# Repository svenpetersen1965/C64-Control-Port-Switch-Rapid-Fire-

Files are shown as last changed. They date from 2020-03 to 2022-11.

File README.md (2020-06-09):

# C64-Control-Port-Switch-Rapid-Fire-
This is a Control Port Switch for the Commodore C64. It provides a rapid fire function. Other than an auto fire function, it fires only as long as the fire button is pressed. And the firing is synchronized with pressing this button. The delay is <= 1msec - the human reaction time is about 300msec.

The micro controller is a (Arduino) Pro Micro. This way, no fancy tools are required for uploading the firmware (just a micro usb B cable).

Find some info on the required cable making <a href="http://tech.guitarsite.de/cable_making.html">on my website</a>

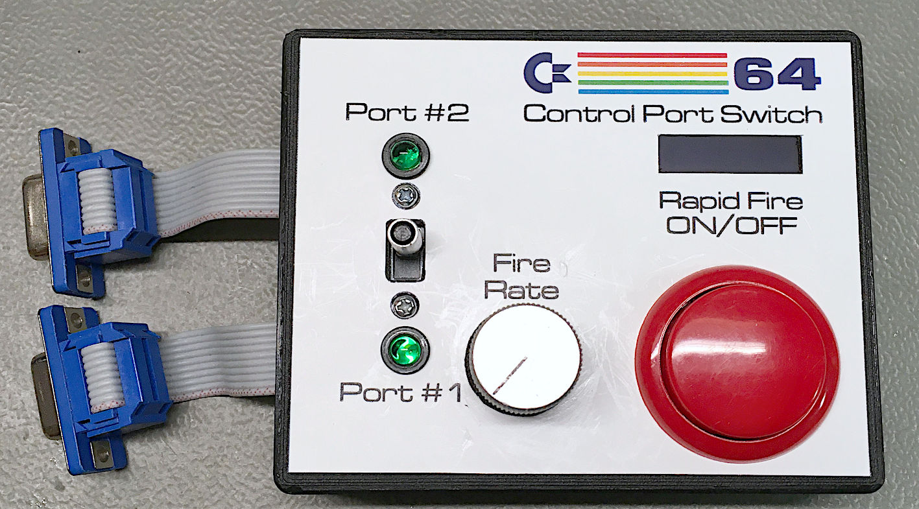
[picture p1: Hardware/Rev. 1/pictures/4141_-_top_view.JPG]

Completed project

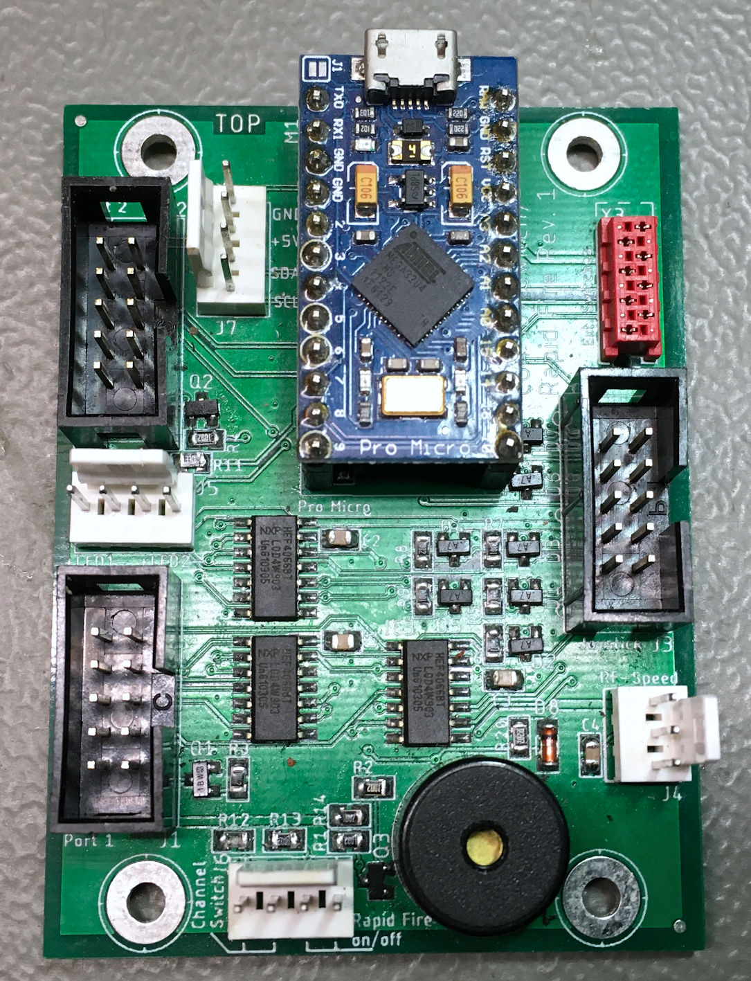
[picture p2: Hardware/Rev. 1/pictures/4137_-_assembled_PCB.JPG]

The PCB

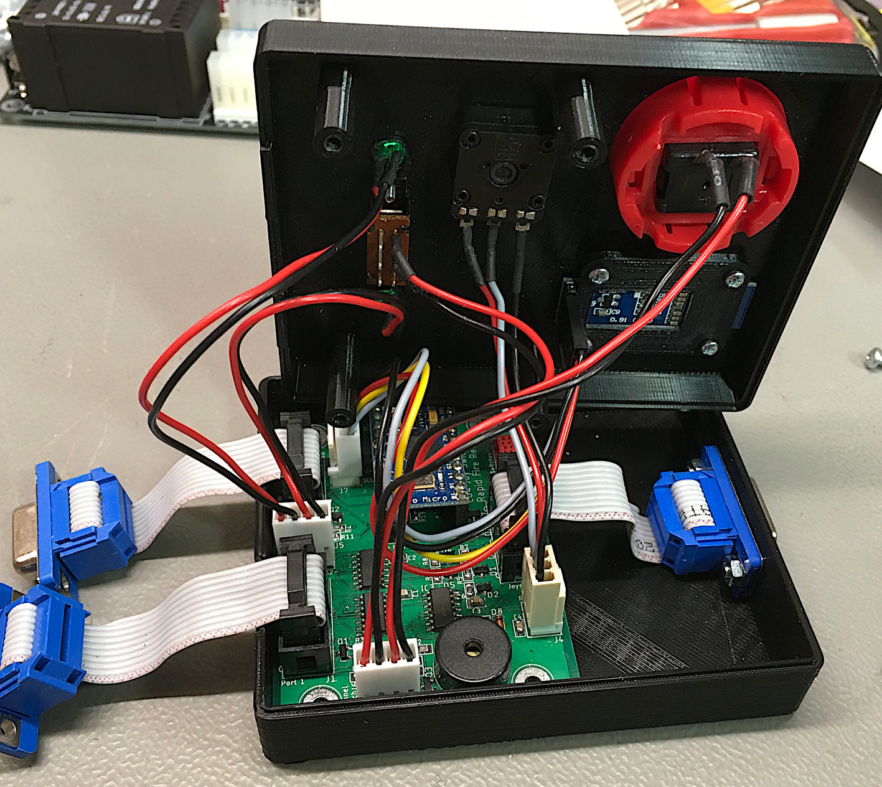
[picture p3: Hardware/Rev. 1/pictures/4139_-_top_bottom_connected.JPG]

The guts

# Recommended Screws
Those are mentioned in the documentation.

# Component Price
The price for the components and PCB was calculated. It is 20.49€ without the 3D printed case (as of June 8th, 2020). The components can be bought cheaper, in case the Pro Micro is bought from AliExpress or Ebay (non domestic).

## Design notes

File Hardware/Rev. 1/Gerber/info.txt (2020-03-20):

      
       Board: C64_Joyswitch_RF
       Rev.:  1
  
       Files:
       ======
  
       All Gerber files are generated in extended gerber format (RS274X)
       *.TOP        : Film top copper
       *.BOT        :  -"- bottom copper
       *.STC        :  -"- top soldermask 
       *.STS        :  -"- bottom soldermask
       *.PLC        :  -"- silk screen top
       *.CRC        :  -"- cream top
       *.DK         : Drills plated Through (Excellon)
       *.NDK        : Drills not plated Through (Excellon)
       *.OUT        : Board outline

       Board Size:
       ===========
       Length     :   72.0 mm
       Width      :   55.0 mm
       Thickness  :   1.6 mm
       Material   :   FR 4
       Copper     :   35 um
       Surface    :   HASL
       
       Remarks:
       ========

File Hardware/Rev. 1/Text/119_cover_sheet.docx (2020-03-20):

Project Documentation

C64 – Joystick Switch & Rapid-Fire

Project number: 119

Revision: 1

Date: 18.03.2020

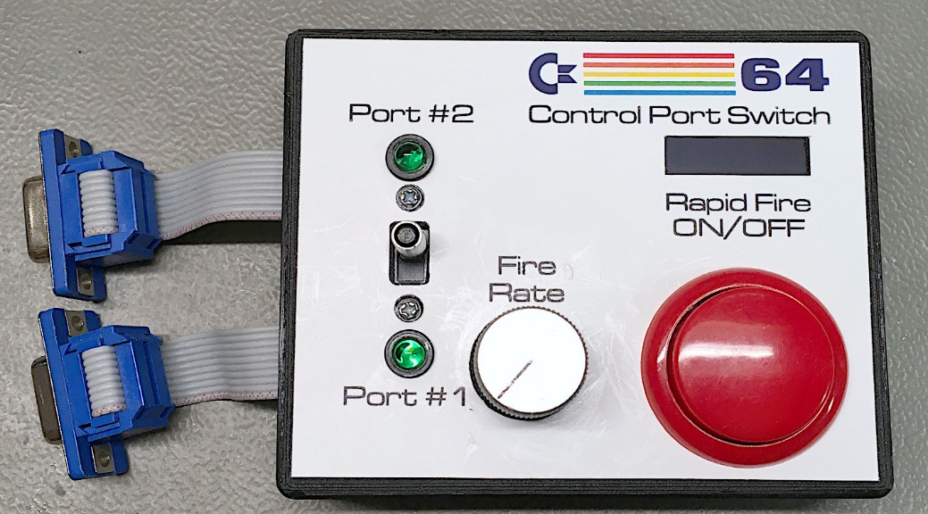
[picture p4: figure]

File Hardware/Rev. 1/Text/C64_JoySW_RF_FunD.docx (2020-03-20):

C64 – Control Port Switch & Rapid-Fire Rev. 1

Functional Description

J1 connects top Control Port 1, J2 to Control Port 2. The switching functionality to the four direction channels (JOY0…3) of the joystick is realized in IC1 and IC2. A HIGH level on signal PORT1 switches on the analog switches of IC1 to the active state, while IC2 is switched off. The joystick signals are available on J1 (JOYA0…3).

A HIGH level on signal PORT2 switches IC1 off (PORT1 is the inverted PORT2), while IC2 is switched on. JOY0…3 are now present on JOYB0…3 (J2, Port 2).

The analog signals POTX and POTY are switched with the analog switch IC2. Q3 and R1 invert the signal PORT2. A HIGH level on the resulting Signal PORT1 is switching POTX to POTXA and POTY to POTYA on control port 1.

A HIGH level on PORT2 switches POTX to POTXB and POTY to POTYB (control port 2).

Both Fire signals (FIREA and FIREB) are generated by the micro controller module M1, a Pro Micro. Q1 and Q2 serve as switches. HIGH pulses on the signals FIRE1 and FIRE2 respectively issue LOW pulses on FIREA and FIREB respectively. LOW means, that the fire is active.

/LED1 and /LED2 should indicate the active control port. /SWITCH and /RF_ON are active LOW signals from external switches, the purpose is switching between channels and switching on/off the rapid-fire function.

The FIRE signal is issued by the connected joystick. It is active LOW. The controller is supervising this signal and issuing the HIGH level or pulses on FIRE1 or FIRE, depending on the rapid-fire option is switched off or on and the port, which is selected.

The signal RFSPEED is a voltage level depending on the position of the connected “Speed” potentiometer. The controller is converting it to digital internally.

J7 carries the I²C bus signals of the controller and supply voltage (+5V) and ground. The purpose is connecting an I²C bus LCD or OLED display. This can serve to indicate the state and rapid-fire rate.

The twin diodes D1…D7 serve as a basic protection of the joystick input. The digital joystick inputs are connected to 10k pull-up resistors.

IC4 is not necessarily populated. It is an EEPROM and can be used to store parameters that should be non-volatile. It is only required, if the scrip for the Pro Micro supports this feature.

The circuitry around Q5 is driving a piezo buzzer. It is an option and only required, in case the firmware (script) for the Pro Micro supports this feature.

C64_JoySW_RF_FunD.docx 18.03.2020 21:15 Drafted by Sven Petersen Page 2 of 2 Doc.-No.: 000-6-00-00

C64_JoySW_RF_FunD.docx 18.03.2020 21:15 Drafted by Sven Petersen Page 1 of 1 Doc.-No.: 119-6-02-01

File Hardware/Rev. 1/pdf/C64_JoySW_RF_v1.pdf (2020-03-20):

# Project Documentation

## C64 – Joystick Switch & Rapid-Fire

## Project number: 119

## Revision: 1

## Date: 18.03.2020

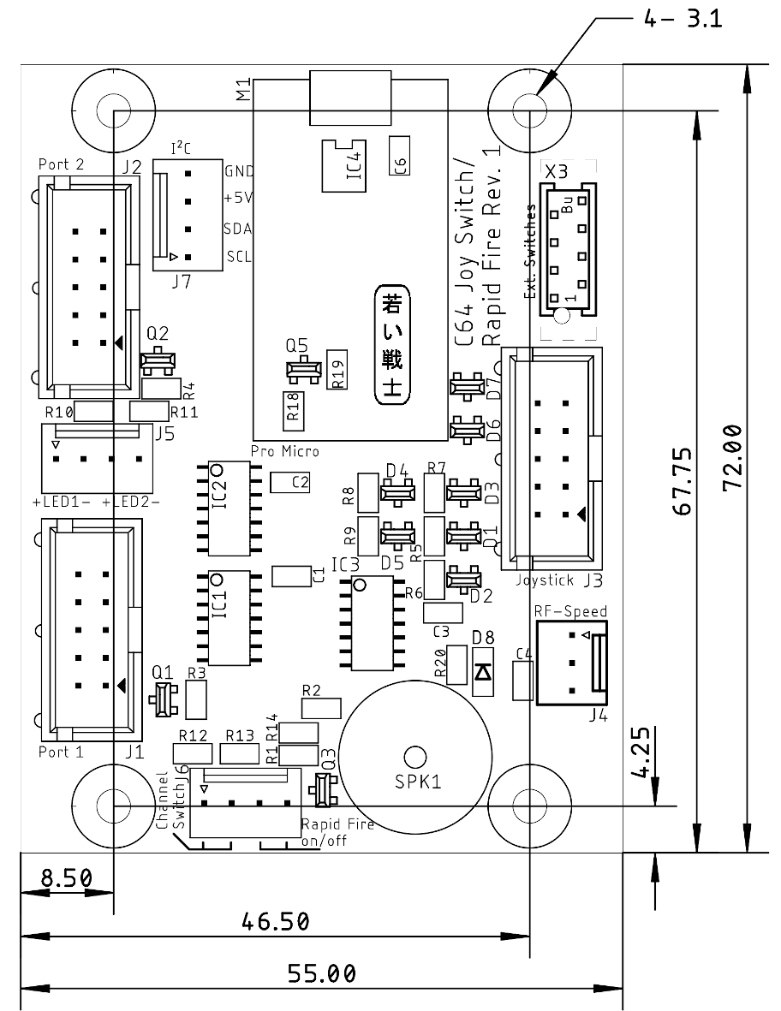
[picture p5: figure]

C64_JoySW_RF_ModD.docx | | 20.03.2020 15:00
Drafted by Sven Petersen | Page 1 of 16 | Doc.-No.: 119-6-01-01

### C64 – Control Port Switch & Rapid-Fire Rev. 1

### Module Description

Most C64 games require the joystick being connected to Control Port 2. Some games, especially those written in the early years of the C64, want the joystick on Control Port 1. To save the hassle of connecting the joystick back and forth, this joystick switch is does it on pressing a button. The selected port is displayed with an LED. The POTX and POTY signal for the paddles is switched as well.

Also, a rapid-fire function is implemented, which is synchronized to the fire button. That means, it starts firing immediately after the fire button was pressed (the maximum delay is 1 ms) at an adjustable frequency. This way, an optimized frequency can be set for every game individually.

The micro controller, which is used in this project is a Pro Micro. They are available for cheap on Ebay and from other online shops, they can be programmed with the free Arduino Software and only a Micro-USB cable is required for the in-system programming of this controller. A I²C connection allows to connect an OLED display to visualize the fire rate.

Figure 1: Dimensions of the PCB

A 3D printed case is provided with the project data. Alternatively it fist into the Reichelt RND
455-00959.

For future expansions, a serial (I²C) EEPROM (IC4) can be installed as a non-volatile memory. Also, the connector X3 is not required.

## Programming the Pro Micro

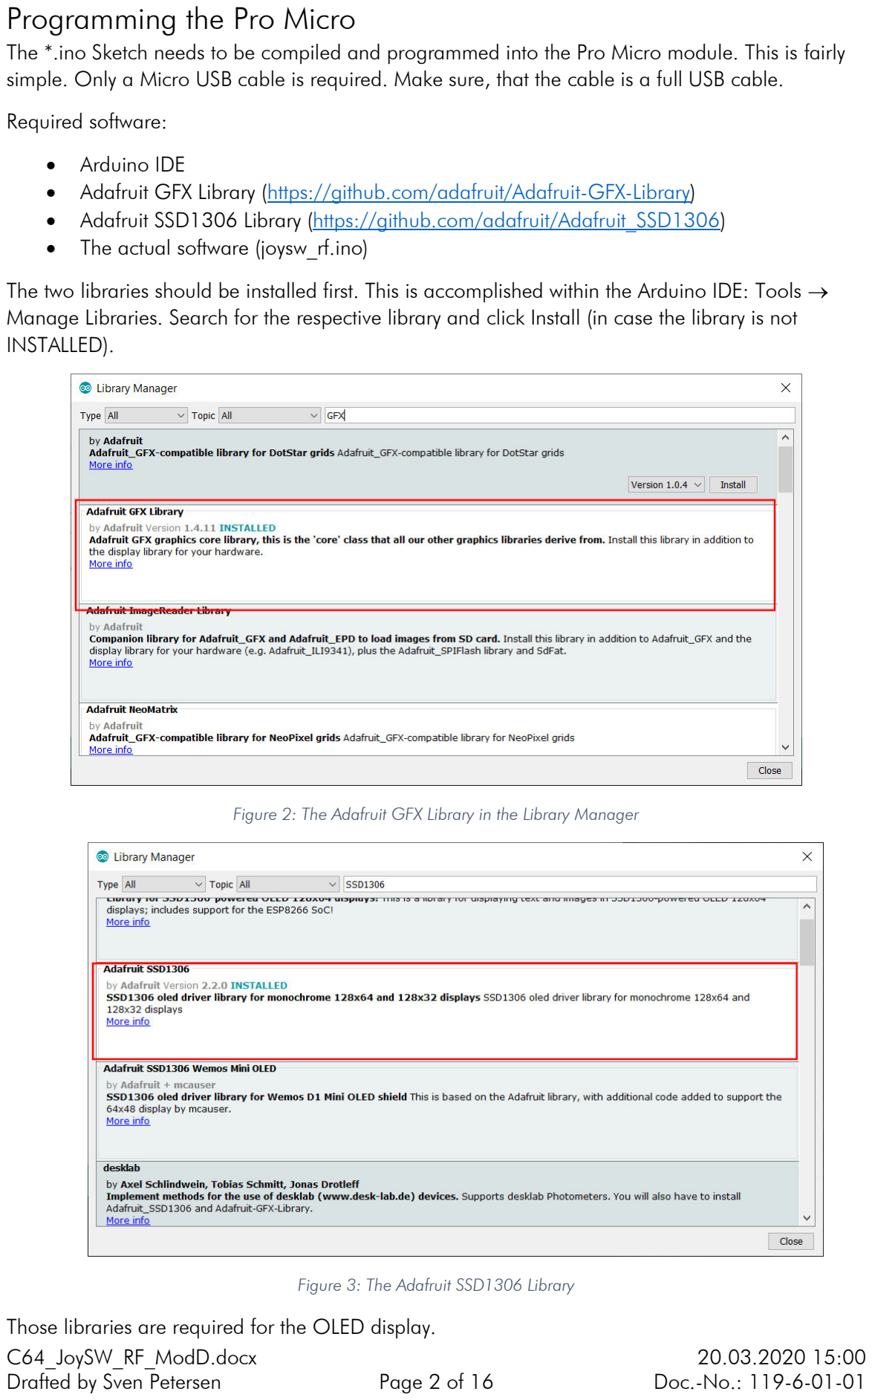
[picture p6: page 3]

Drafted by Sven Petersen | Page 2 of 16 | Doc.-No.: 119-6-01-01

The *.ino Sketch needs to be compiled and programmed into the Pro Micro module. This is fairly simple. Only a Micro USB cable is required. Make sure, that the cable is a full USB cable.

Required software:

- Arduino IDE
- Adafruit GFX Library (https://github.com/adafruit/Adafruit-GFX-Library)
- Adafruit SSD1306 Library (https://github.com/adafruit/Adafruit_SSD1306)
- The actual software (joysw_rf.ino)

The two libraries should be installed first. This is accomplished within the Arduino IDE: Tools → Manage Libraries. Search for the respective library and click Install (in case the library is not INSTALLED).

Figure 2: The Adafruit GFX Library in the Library Manager

Figure 3: The Adafruit SSD1306 Library

Those libraries are required for the OLED display.

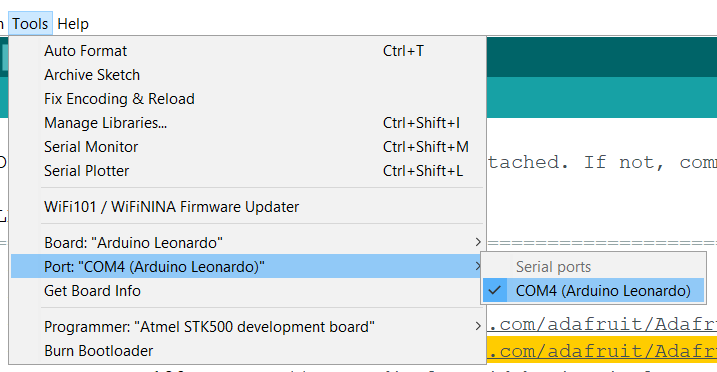
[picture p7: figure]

Drafted by Sven Petersen | Page 3 of 16 | Doc.-No.: 119-6-01-01

Next is selecting the type of Arduino. The Pro Micro is acting like a Leonardo. So in the Arduino IDE, you have to select Tools → Board → Arduino Leonardo.

Now make sure, that Pro Micro is connected to the PC via the USB cable (Micro USB). It does not need to be installed in the Control Port Switch. It is powered via USB.

Figure 4: Setting up the board type (Leonardo)
After connecting the Pro Micro, the PC should report a new device is connected. The Pro Micro’s programming interface acts as a serial interface (COM-Port). If not, there might be a problem with the drivers or the Pro Micro is broken.

Now, try to find the COM-Port number, that the Pro Micro is configured as:

Figure 5: Selecting the COM-port
In Tools → Port, this COM-port should be visible. Select it. The COM-port is the serial channel, the Arduino IDE is communication through with the ATmega 32u4 micro controller on the module.

Now you can load the Sketch into the Arduino IDE (File → Open…). The Sketch is the source code of the program. It needs to be compiled (to create a machine program, which the processor understands). In the Arduino IDFE, it is very much simplified. You do not need to care for make-files etc. like in other development environments for micro controllers. If you are not into this topic, Arduino is for you.

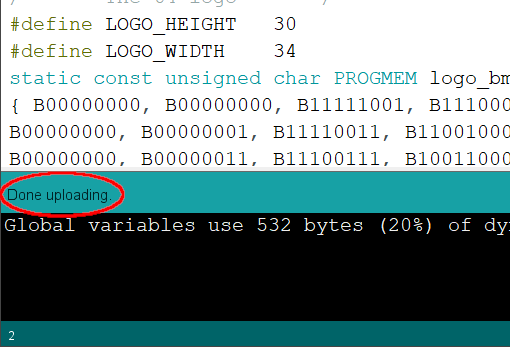
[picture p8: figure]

Drafted by Sven Petersen | Page 4 of 16 | Doc.-No.: 119-6-01-01

You can even edit the source code. In case you do not want to connect a display (which is recommended), you can put // in front of the #define OLED directive. This makes a comment out of it, so it is not effective anymore. You will see a // comment at almost every line. Feel free to look though it, you might find it interesting. Programming is no witchcraft!

So, to compile and upload the sketch, click the right arrow icon at the top left of the Arduino IDE.

Figure 6: Compiling the Sketch and uploading (right arrow)

If all libraries are installed, the correct board type and COM-Port is selected and the Sketch is unmodified, the code should compile and upload without any error messages.

Figure 7: The Upload is done
So, look out for “Done uploading”, like shown in Figure 7. If you don’t see this message, you
should read the error messages, which are displayed in the bottom of the window.

## Wiring the Device

### Crimping

Crimping is the preferred way of making cables, the connections are of a good quality (if the crimping carried out well). Unfortunately, it requires some dedicated tools. Fortunately, there are tools available for a fair price. Good results can be accomplished with the Engineer PA-20 and PA-09 tools. The IWISS IWS-2820 is a cheaper alternative, the results are acceptable.

Those tools are two pass tools. That means, the wire crimp and the isolation crimp have to be
carried out in two consecutive passes. I prefer the “wire crimp first” method. There are plenty video

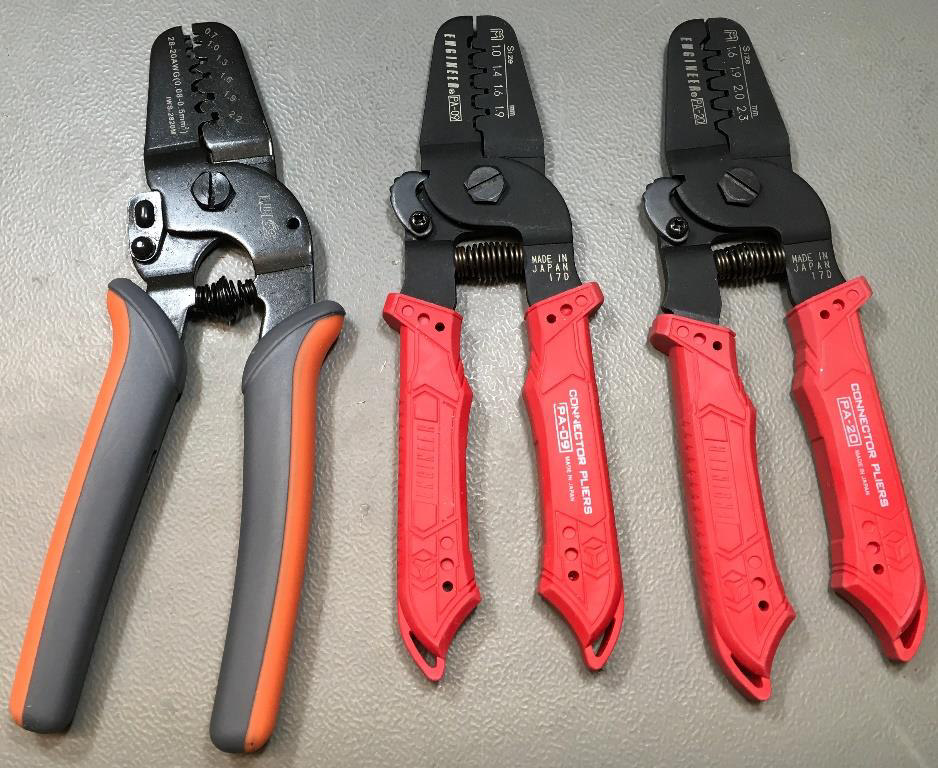
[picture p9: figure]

Drafted by Sven Petersen | Page 5 of 16 | Doc.-No.: 119-6-01-01

tutorials about crimping on Youtube. I also plan to write an essay about crimping on my website (http://tech.guitarsite.de). This is a future project.

Figure 8: My crimp tools (from left to right: IWS-2820, PA-09, PA-20)

After 25 years in industrial engineering, I prefer locking connectors. The widely popular DuPont connectors are also acceptable for hobby projects. They might need to be secured with a drop of silicon glue (hot glue might work, but is harder to separate, if required).
Direct soldering of the wires onto the board, is also a working method, if you don’t have any crimp tools or don’t want to invest in them. It is not really great and it is hard to separate the components
of the built, if required.

### Cables

Figure 9: 2x5 and DSub IDC connectors and strain reliefs

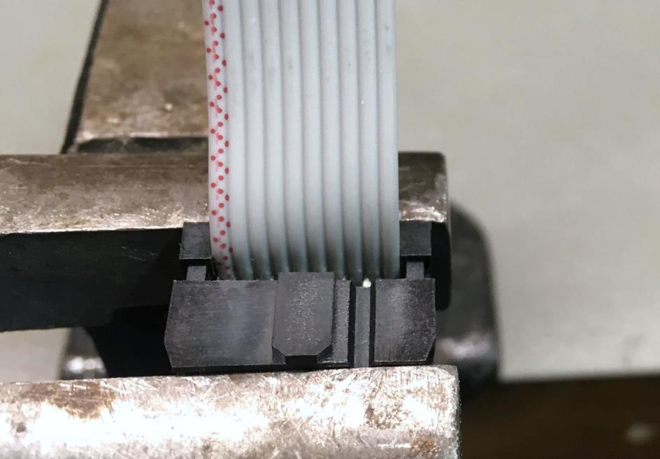
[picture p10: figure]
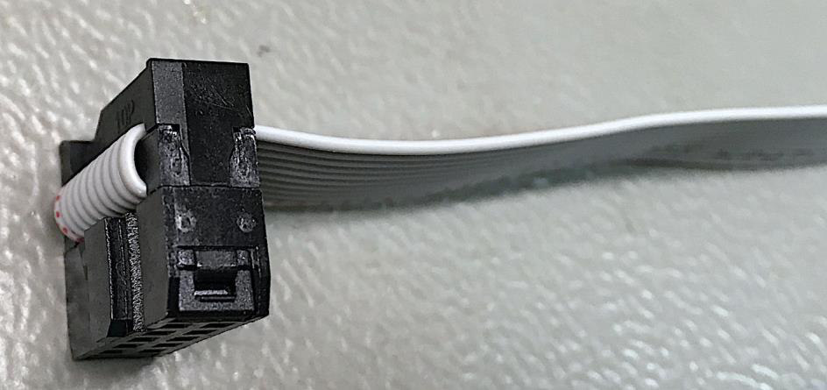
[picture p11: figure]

Drafted by Sven Petersen | Page 6 of 16 | Doc.-No.: 119-6-01-01

There are three ribbon cables, two for the control ports, one for the joystick input. Both types of connectors are IDC (Insulation Displacement Connectors). (https://en.wikipedia.org/wiki/Insulation-displacement_connector) This means, no soldering required, easy make. The little blades on each pin will penetrate the insulation of each wire of the ribbon cable and make a reliable contact with the conductors. It is a technology, which is established since the 1970s.
You don’t even need a special tool for making the cables, just a (little) vice (Figure 10). There is a
strain relief for both connectors, which is installed last. First, you cut the ribbon cable to length. Then insert the ribbon cable and align to the opposite side of the connector. Keep in mind, that installing the strain relief will cause a 180° turn (Figure 11). So, insert the cable from the opposite side that you finally want the cable to leave the connector. Pin 1 is marked. The wire 1 is also marked on a ribbon cable.

All D-Sub 9 connectors only have 9 pins, the IDC connectors have 2x5 (=10) pins. Thus the 10th wire has to be separated before the cable is inserted (Figure 12) in the D-Sub and finally clipped off.

Figure 10: IDC connector before being compressed in a vice

Figure 11: Side view after installing the strain relief

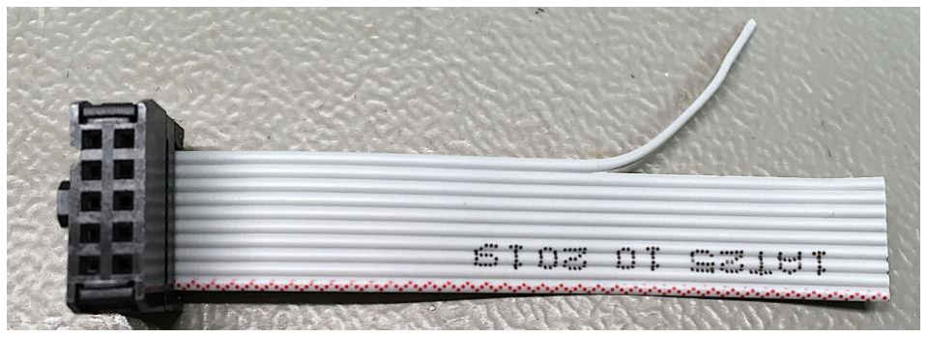
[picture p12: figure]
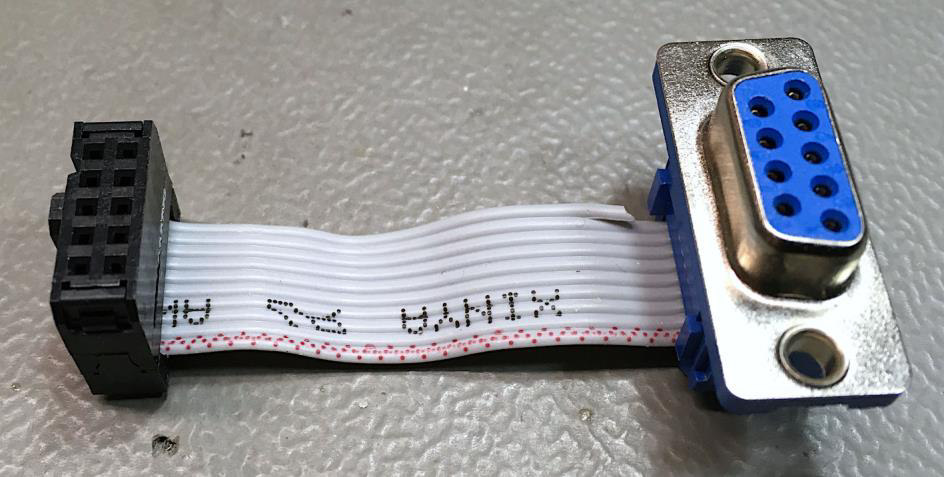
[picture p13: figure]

Drafted by Sven Petersen | Page 7 of 16 | Doc.-No.: 119-6-01-01

Figure 12: Separated 10th wire of the ribbon cable

Keep in mind, that pin 1 is in a deferent position on male and female D-Sub connectors. On a female connector, the pin numbers are usually shown on the contact face.

The required ribbon cables look like this:

Figure 13: Joystick Input cable: Male D-Sub, 8cm ribbon cable

Figure 14: The output cables: female D-Sub, 8cm ribbon cable

Please note the different orientation of the coding notch in Figure 13 and Figure 14. Also, the marked wires (1) of the ribbon cables are on opposite sides. The cable shown in Figure 14 is required twice.

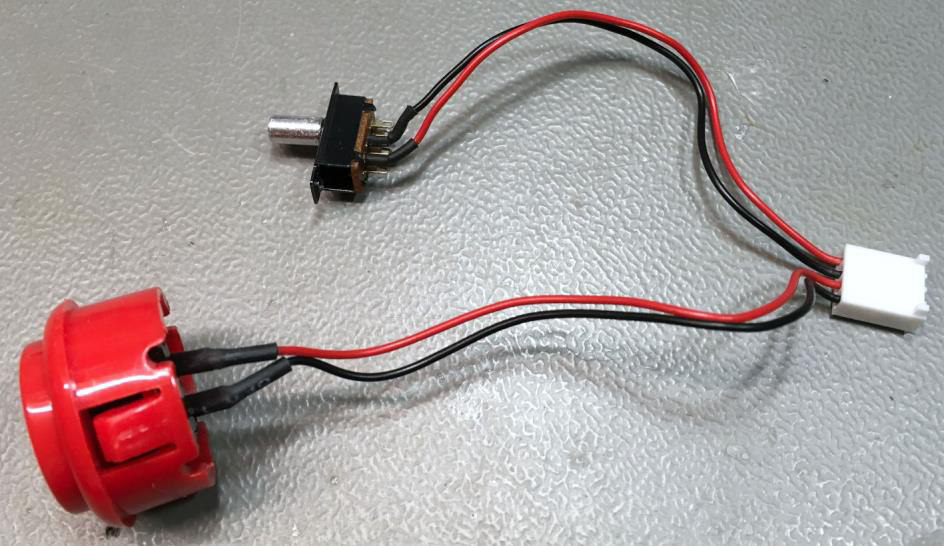
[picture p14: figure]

Drafted by Sven Petersen | Page 8 of 16 | Doc.-No.: 119-6-01-01

Figure 15: The cable with the rapid-fire button and the channel select switch
The rapid-fire button is sold as “30mm arcade button” on ebay or AliExpress. The switch is a panel
mount slide switch, the screw holes (M2) pitch is 19mm. The cable length is 12cm for both switches.

It is advised to use shrinkable sleeve the shown connector is a Molex 22-01-2041 crimp housing (refer to the /Switches). The crimp dies used for the crimp terminal (also for DuPont crimp terminals) are 1.6mm for the wire crimp and 1.9mm for the insulation crimp.

Figure 16: The display cable

DuPont Signal | Color | Molex
Pin 1 | GND | Black | Pin 4
Pin 2 | +5V | Red | Pin 3
Pin 4 | SDA | Yellow | Pin 2
Pin 3 | SCL (also “SCK”) | Grey | Pin 1

Figure 17: 0.91" OLED display
The display is a 0.91” OLED with I²C bus and an SSD1306 controller. The measures of the display
PCB are 38mm x 12mm.

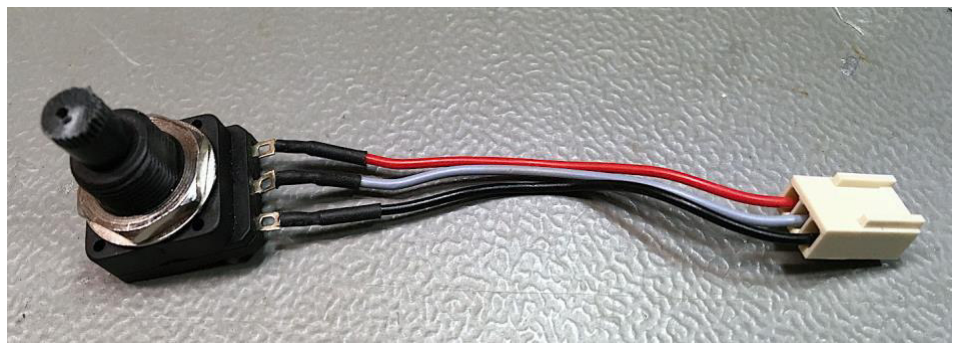
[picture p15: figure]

Drafted by Sven Petersen | Page 9 of 16 | Doc.-No.: 119-6-01-01

Figure 18: Potentiometer cable

The crimp housing is a Molex 22-01-2031. For the connection, please refer to chapter Pinouts/Fire-Rate Potentiometer.Length 6.5cm.

Pot | Signal | Color | Molex
Clockwise | +5V | Black | Pin 1
Tap | RF-Speed | Red | Pin 2
Counter Clockwise | GND | Yellow | Pin 3

Figure 19: LED cable

Again, there is a Molex 22-01-2041 crimp housing (refer to Chapter Pinouts/LEDs). Note: The LEDs have a polarity. The anode (+) and the cathode (-) must not be confused. The cathode is marked with the flat side. Also, the cathode pin is shorter. It is advised to use shrinkable sleeves for the solder joints. Length: 8cm.

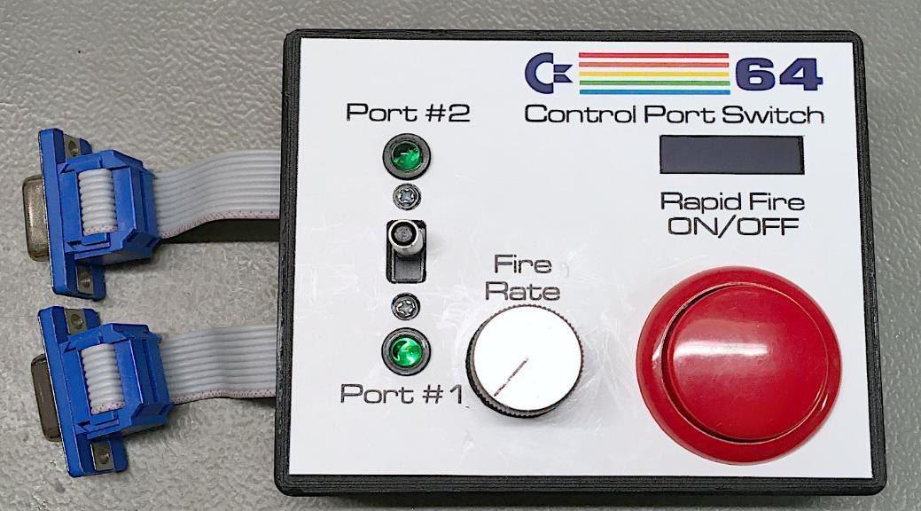
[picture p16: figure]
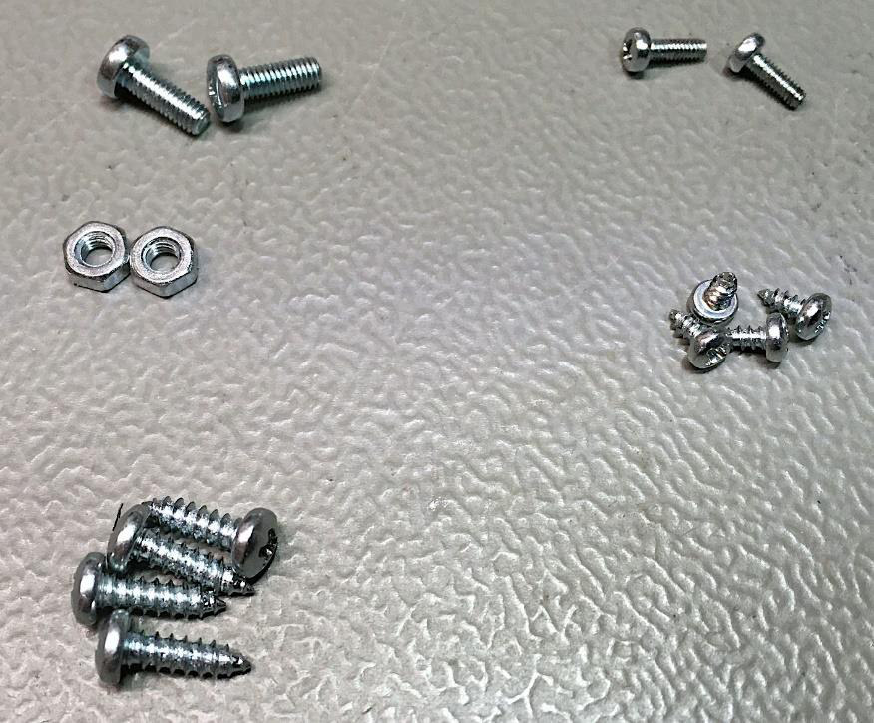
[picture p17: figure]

Drafted by Sven Petersen | Page 10 of 16 | Doc.-No.: 119-6-01-01

## Assembly

The 3D printed housing consists of three parts and a label. Also, some screws are required.

Figure 20: Top view of the completed Control Port Switch

The label is printed on a weatherproof outdoor sticker (I have used HERMA 9500) for laser printing (on my Samsung C1810W color laser printer). Other brands are also suitable. The foil sticks very well.

The top shell, bottom shell and display holder were printed with PLA filament.

Assembling the PCB is pretty straight forward. First populate the surface mount parts (SMD). The Pro Micro might require the pin headers being soldered. To get good and vertical connections, insert the pin headers into the socket strips into the PCB and solder the Pro Micro first. Then solder the socket strips in the PCB.

The through hole parts are soldered last.

Before mounting any parts in the top shell, the label should be installed.

Figure 21: The required screws

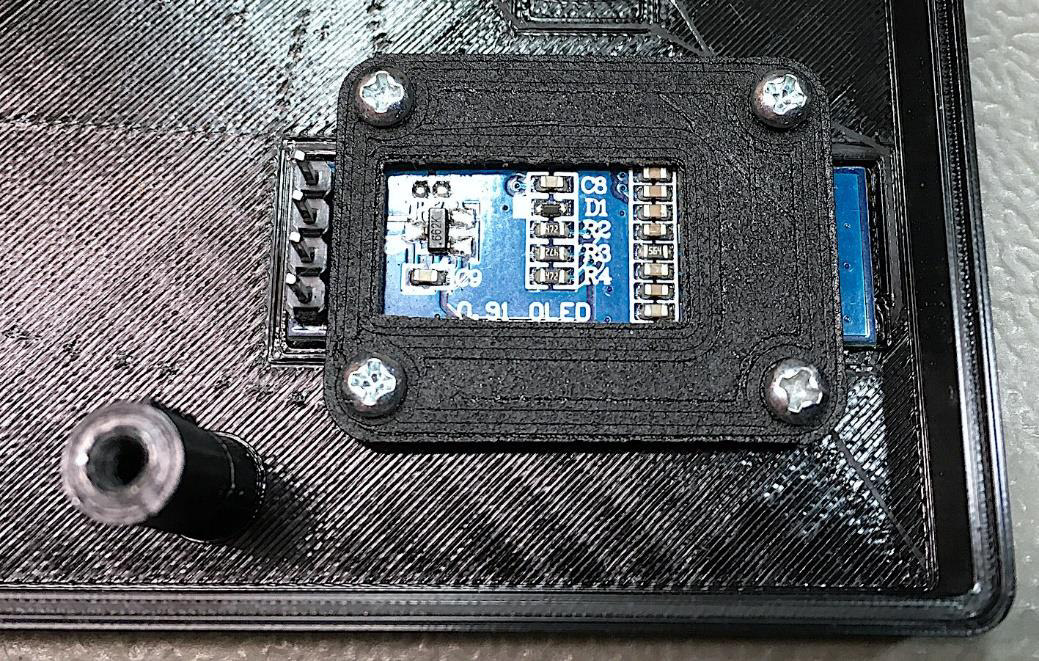
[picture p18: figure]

Drafted by Sven Petersen | Page 11 of 16 | Doc.-No.: 119-6-01-01

The following screws are required

- 2x M3x8 and M3 nuts for the D-Sub connector (Joystick input). Non-Metric screws are possible.
- 2x M2x6 for the slide switch
- 4x C2.2x4.5 for the display holder
- 4x C2.9x9.5 for the case

The tolerances of the display cutout and the display holder are +/-0.5mm, so such a display should fit in, although the tolerances might be high. Nevertheless, the display should be handles with care. The glass is thin and breaks easily. So, make sure, the display fits before you (carefully) tighten the screws (4x C2.2x4.5). Refer to Figure 22.

Figure 22: Mounted display

Mount the potentiometer. The pins should point inwards(Figure 23).

The cable with the arcade button can be mounted by inserting the slide switch through the hole. The arcade button snaps in place. There are different arcade buttons available, which might be slightly different. In case the arcade button sits lose, some hot glue can cure that. Do not apply the hot glues near the (open) sides, because it will block the button. Only apply it near the snap-in pins.

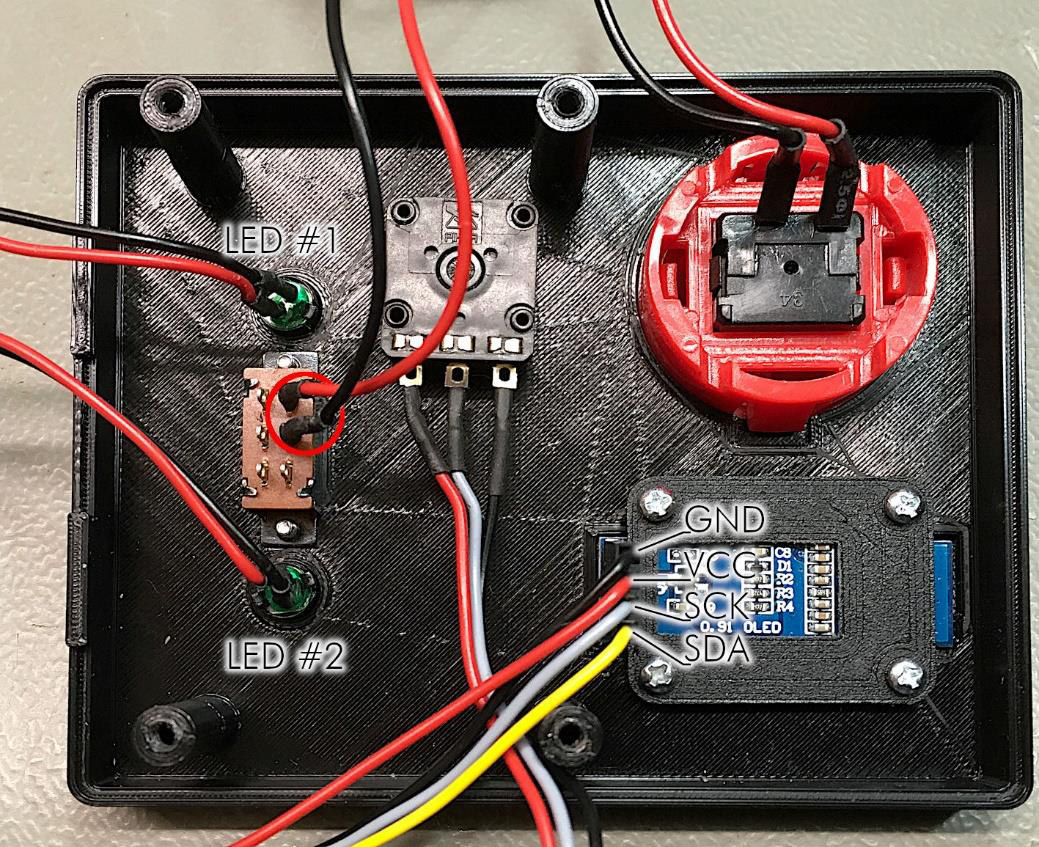
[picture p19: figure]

Drafted by Sven Petersen | Page 12 of 16 | Doc.-No.: 119-6-01-01

Figure 23: The completely assembled top shell

Fix the slide switch with two screws (M2x6). The two connected terminals of the slide switch should point to the side with the pot and the arcade button. Only this way, it will switch to Port #1 when slid downwards (red circle in Figure 23).

For the LEDs, snap in the LED holders and insert the LEDs. They could be confused, so make sure, that the LEDs are mounted in the place, they belong. Refer to Figure 19 and Figure 23.

Finally, mount the display cable. This can be oriented improperly. Refer to Figure 16 and Figure 23.
Assembling the bottom shell is not much work. The joystick input cable (“Male”) is screwed to the
bottom with two screws (M3x8 and M3 nuts). Refer to Figure 24.

Figure 24: Assembled bottom shell

Put the PCB in place and connect the ribbon cables. The PCB is not yet held in place by screws.

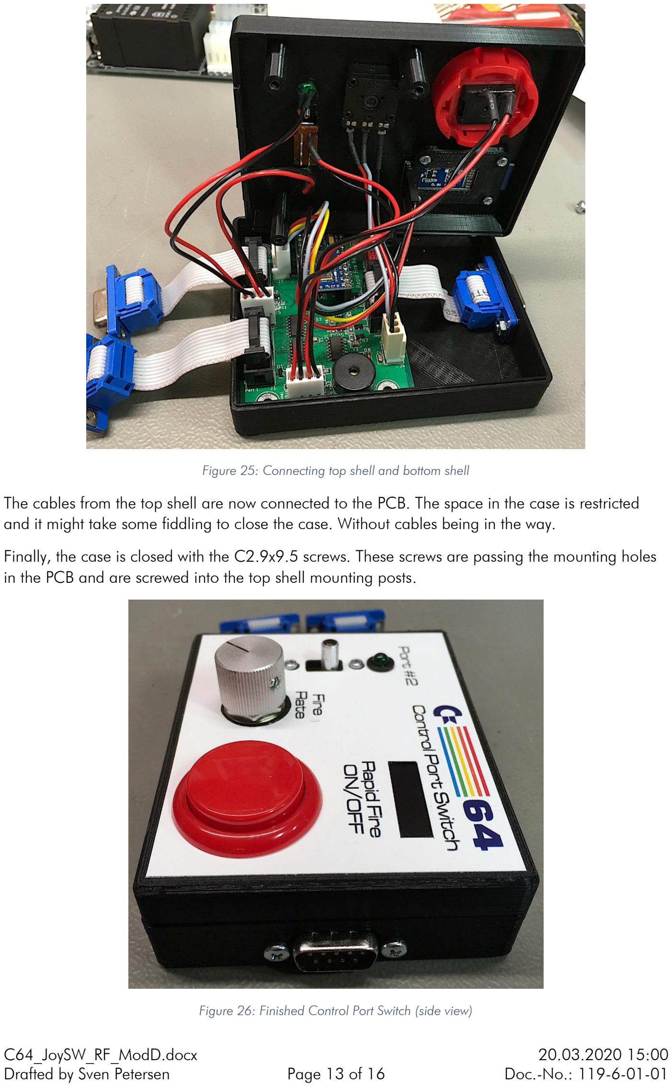
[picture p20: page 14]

Drafted by Sven Petersen | Page 13 of 16 | Doc.-No.: 119-6-01-01

Figure 25: Connecting top shell and bottom shell

The cables from the top shell are now connected to the PCB. The space in the case is restricted and it might take some fiddling to close the case. Without cables being in the way.

Finally, the case is closed with the C2.9x9.5 screws. These screws are passing the mounting holes in the PCB and are screwed into the top shell mounting posts.

Figure 26: Finished Control Port Switch (side view)

Drafted by Sven Petersen | Page 14 of 16 | Doc.-No.: 119-6-01-01

## Test of the Control Port Switch

For testing, I have used the Joytester II, (https://csdb.dk/release/?id=170175) which can be found on csdb.dk.

Connect the Control Port Switch to the C64, then switch on the computer. The Control Port Switch will issue a beep (1/4 second). The display should first show the 64 logo, then a link to my website (sorry for advertising).

The port selector switch selects one port and the corresponding LED should light up. Sliding the switch to the opposite side should select the other port.

Pushing the arcade button should switch on the rapid-fire. This is displayed on the OLED display. The LED of the selected Port should blink while rapid-fire is on. The blink rate resembles the fire rate. Turn the pot CCW and the fire rate gets less (150 r/min is the minimum in the present software), turning the pot clockwise should increase the fire rate (1500 r/min is the maximum in the present software).

Now load the software and connect the joystick. The joystick should be active on the selected port. All four directions and the fire button should be tested for both ports. They should show some activity on the selected port only.

## Trouble Shooting

Make sure, that the cables are connected properly and that the single wires are not confused.

In case the device is dead (no sound, no light, no display), make sure, the Pro Micro is programmed.

Check the orientation of the ICs on the board, check the soldering.

## Pinouts

### Control Ports

J1 (Port 1) & J2 (Port 2) – 2x5 pin header (box connector) for a ribbon cable which connects via a D-SUB 9 (female) to the control port.

Pin D-SUB Signal | Pin D-SUB Signal
1 | 1 | JOY0 (up) | 2 | 6 | FIRE
3 | 2 | JOY1 (down) | 4 | 7 | +5V
5 | 3 | JOY2 (left) | 6 | 8 | GND
7 | 4 | JOY3 (right) | 8 | 9 | POTX
9 | 5 | POTY | 10 | - | n.c.

### Joystick Port

J3 – 2x5 pin header (box connector) for a ribbon cable which connects via a D-SUB 9 (male) to the control port.

Pin D-SUB Signal | Pin D-SUB Signal
1 | 1 | JOY0 (up) | 2 | 6 | FIRE
3 | 2 | JOY1 (down) | 4 | 7 | +5V
5 | 3 | JOY2 (left) | 6 | 8 | GND
7 | 4 | JOY3 (right) | 8 | 9 | POTX
9 | 5 | POTY | 10 | - | n.c.

Drafted by Sven Petersen | Page 15 of 16 | Doc.-No.: 119-6-01-01

### Fire-Rate Potentiometer

J4 – 3p. Molex 22-27-2031 (2,54mm pitch pin header, friction lock). Mating crimp housing 22-01-2031. Crimp terminal: 2478-TL/0850-0106.

Alternatively, a 2.54mm pitch standard pin header and a Dupont crimp housing and terminals can be used or the potentiometer is wired and soldered in without any connectors.

Pin | Signal | Note
1 | +5V | Clockwise
2 | RFSPEED | Tap
3 | GND | Counterclockwise

### Switches

J6 – 4p. Molex 22-27-2041 (2,54mm pitch pin header, friction lock). Mating crimp housing 22-01-2041. Crimp terminal: 2478-TL/0850-0106.

Alternatively, a 2.54mm pitch standard pin header and a DuPont crimp housing and terminals can be used or the switches are wired and soldered in without any connectors.

Pin | Signal | Note
1 | /SWITCH | Switch for channel switching
2 | GND | The other connection for this switch
3 | /RF_ON | Switch for rapid-fire
4 | GND | The other connection for this switch

### LEDs

J5 – 4p. Molex 22-27-2041 (2,54mm pitch pin header, friction lock). Mating crimp housing 22-01-2041. Crimp terminal: 2478-TL/0850-0106.

Alternatively, a 2.54mm pitch standard pin header and a Dupont crimp housing and terminals can be used or the LEDs are wired and soldered in without any connectors.

Pin | Signal | Note
1 | +5V | Anode of LED for Port 1 active
2 | /LED1 | Cathode LED1, 330Ω resistor on PCB
3 | +5V | Anode of LED for Port 2 active
4 | /LED2 | Cathode LED2, 330Ω resistor on PCB

### I²C-Bus

J7 – 4p. Molex 22-27-2041 (2,54mm pitch pin header, friction lock). Mating crimp housing 22-01-2041. Crimp terminal: 2478-TL/0850-0106.

Drafted by Sven Petersen | Page 16 of 16 | Doc.-No.: 119-6-01-01

The I²C bus provides a display connection. The total power consumption of the board, the display and the joystick should not exceed 100mA.

Pin | Signal | Note
1 | SCL | I²C Clock
2 | SDA | I²C Data
3 | +5V | Supply voltage (I < 100mA)
4 | GND | Ground

### External Switches

X3 – MPE Garry 369-1-008 (MicroMatch 8p., female, THT).

This is an optional connector to operate this module with an external switch board (Project No.
112) or rotary encoder board (Project No. 118) from the Pi1541 Project. Both boards are suitable for +5V supply, except the LEDs, which then should remain not assembled.
Pin | Signal | Note
1 | /SW1_IN | Select
2 | /SW2_IN | Up
3 | /SW3_IN | Down
4 | /SWITCH | Channel Switching
5 | /RF_ON | Rapid-fire on/off
6 | - | Not connected
7 | +5V | Power supply for external switches
8 | GND | Ground

## Links

- My github: https://github.com/svenpetersen1965
- My website: http://tech.guitarsite.de/
- Arduino IDE: https://www.arduino.cc/en/Main/Software
- The test software: https://csdb.dk/release/?id=170175
- A source of the OLED display: AliExpress: 1pcs 0.91 inch OLED module 0.91" white/blue OLED 128X32 OLED LCD LED Display Module 0.91" IIC Communicate (https://www.aliexpress.com/item/32672327708.html?spm=a2g0s.9042311.0.0.715d4c4dBON0hL)
- A source of the arcade button: AliExpress: 10 pcs Arcade 30mm Round Button Copy SANWA OBSF-30 (https://www.aliexpress.com/item/10000014730221.html?spm=a2g0s.9042311.0.0.27424c4dlqOZNp)
- A source of the Pro Micro: AliExpress: TZT Pro Micro ATmega32U4 5V 16MHz Replace ATmega328 For Arduino Pro Mini With 2 Row Pin Header For Leonardo Mini Usb Interface (https://www.aliexpress.com/item/32768308647.html)

Note: The sources are one of plenty.

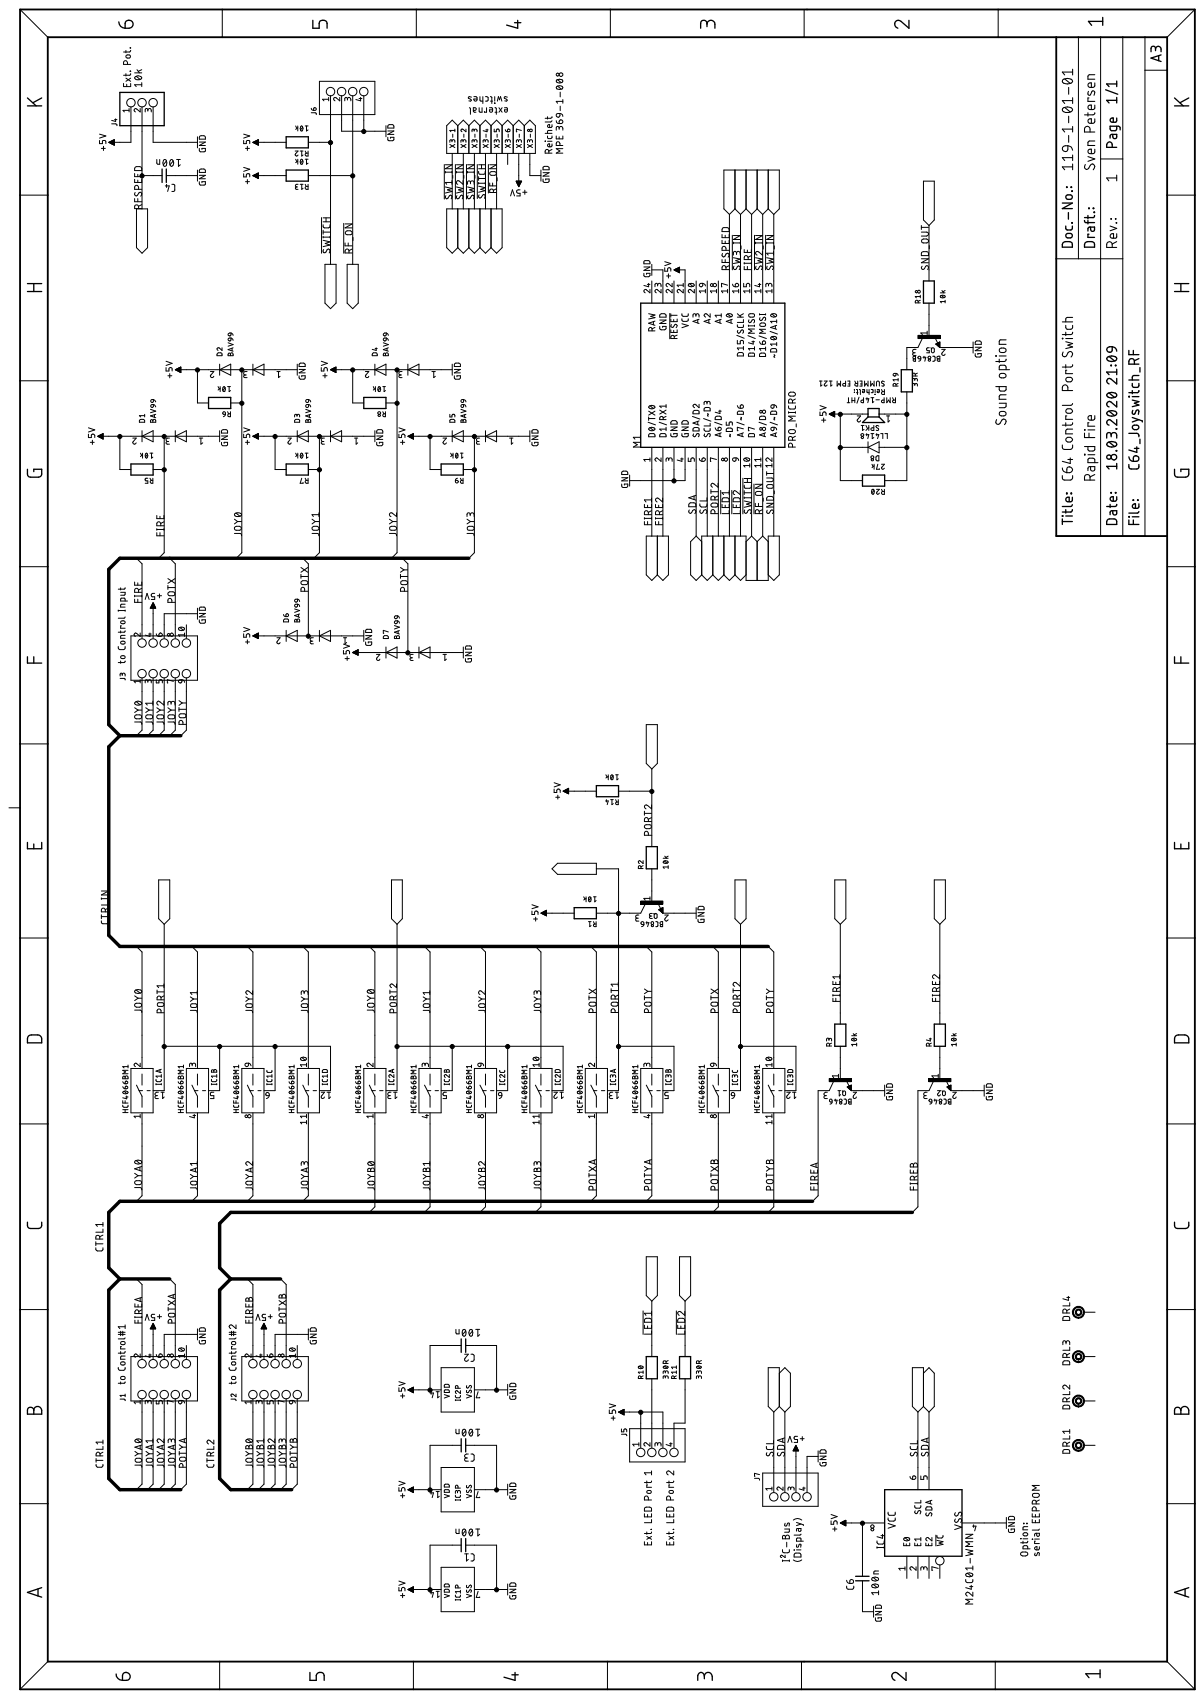
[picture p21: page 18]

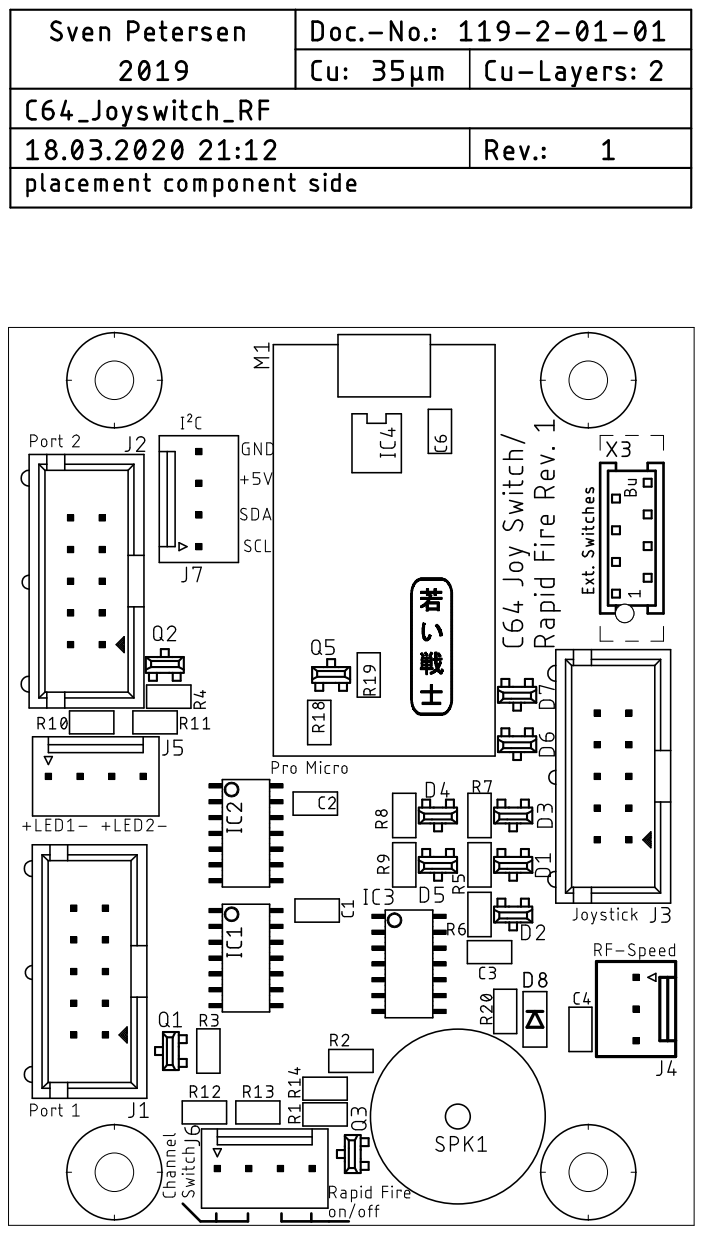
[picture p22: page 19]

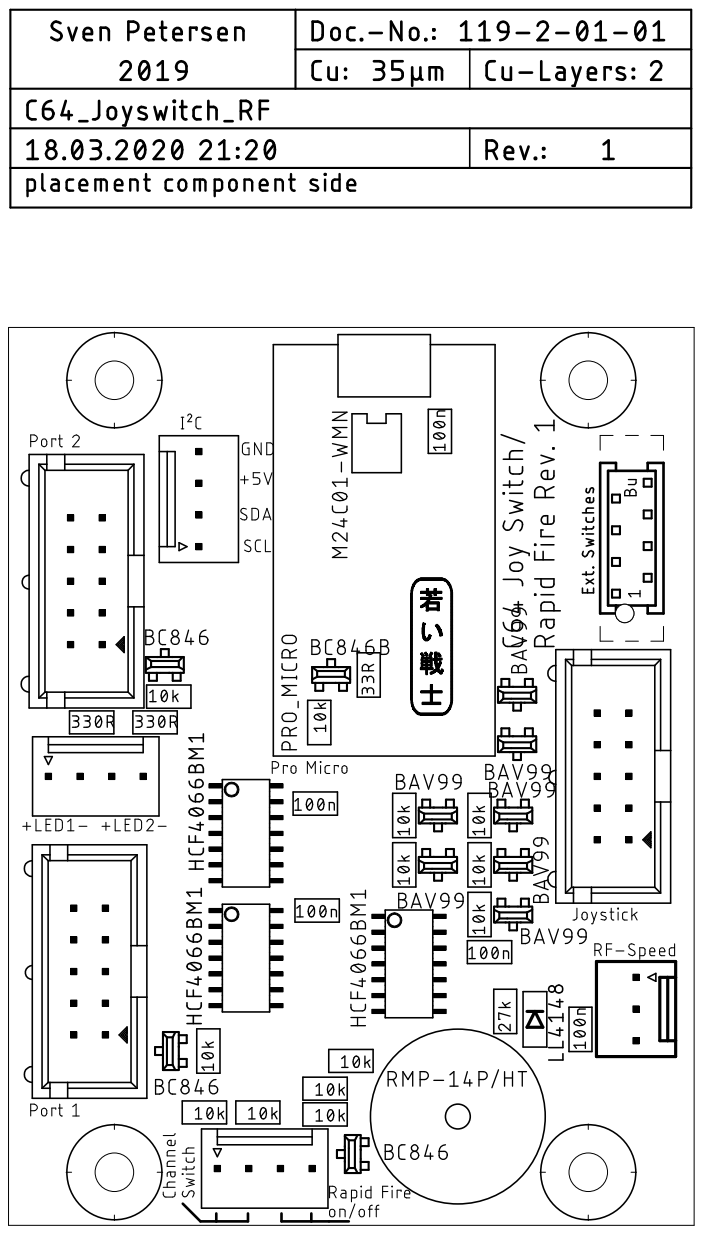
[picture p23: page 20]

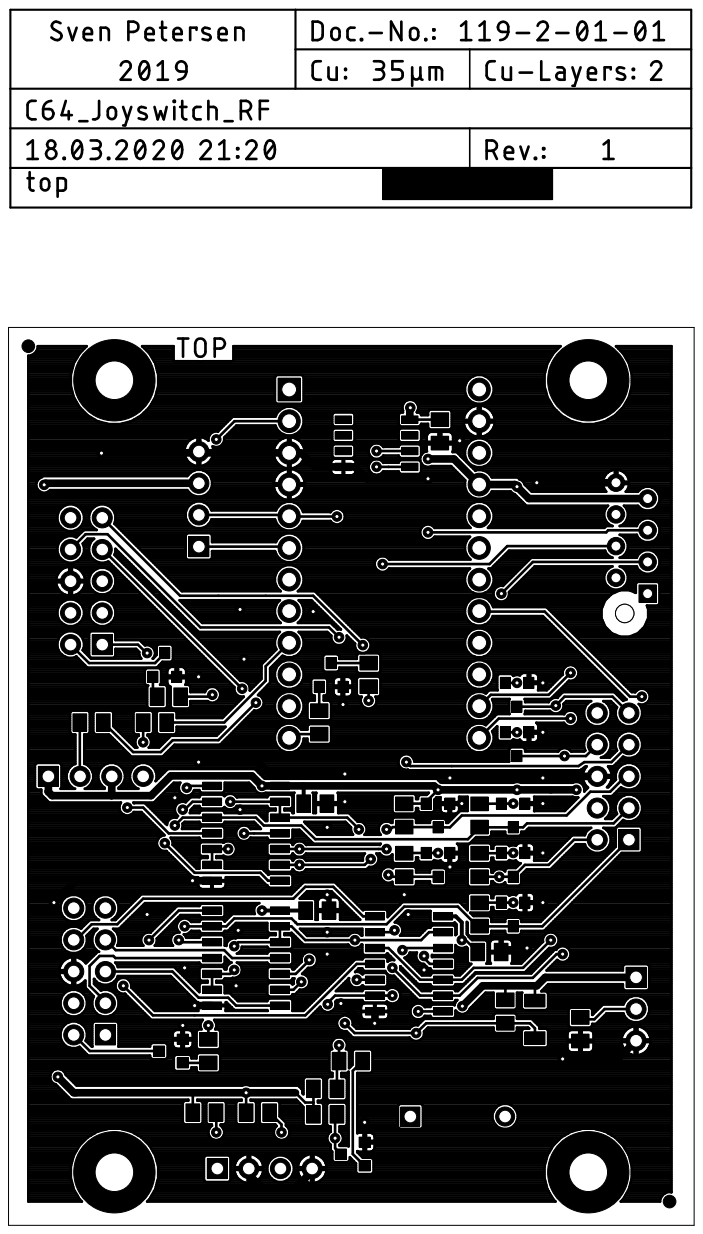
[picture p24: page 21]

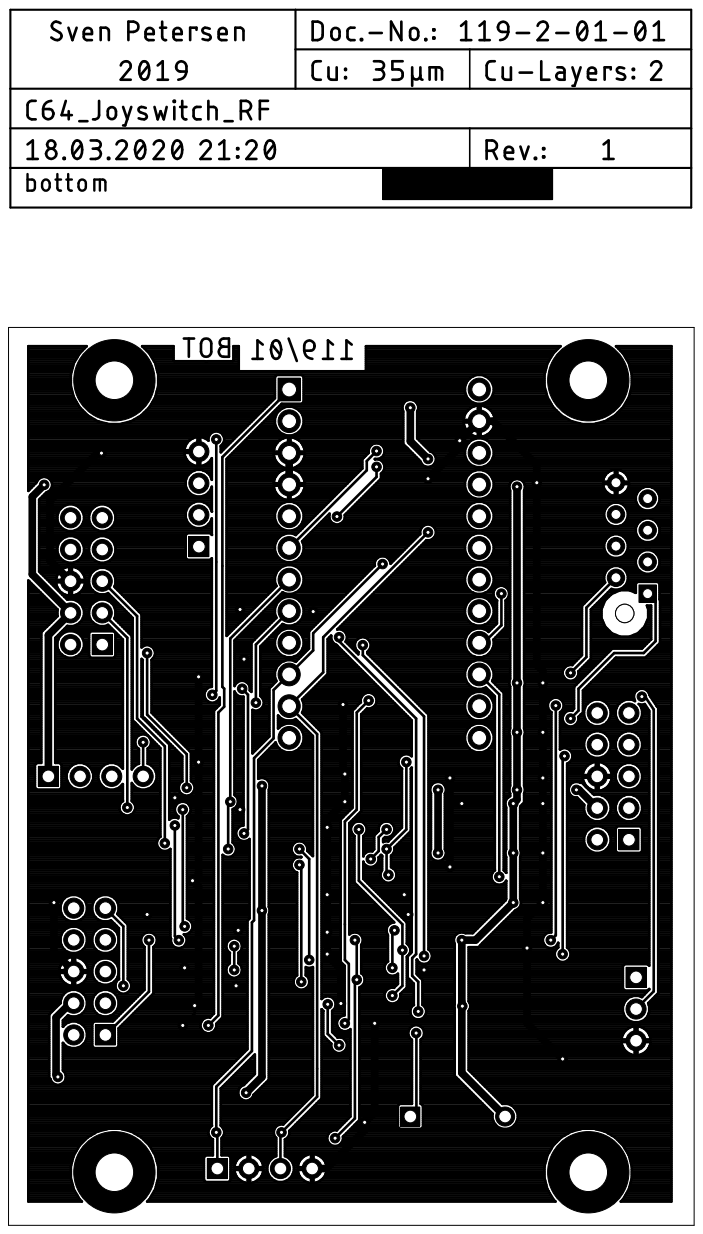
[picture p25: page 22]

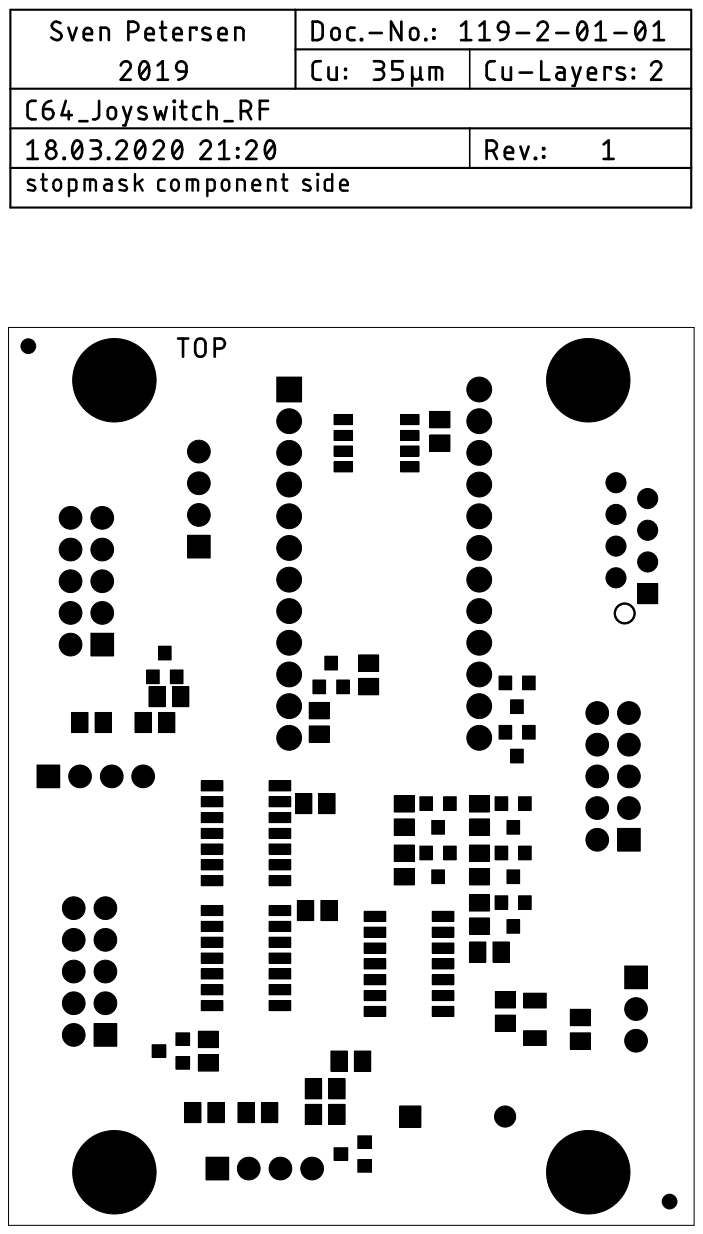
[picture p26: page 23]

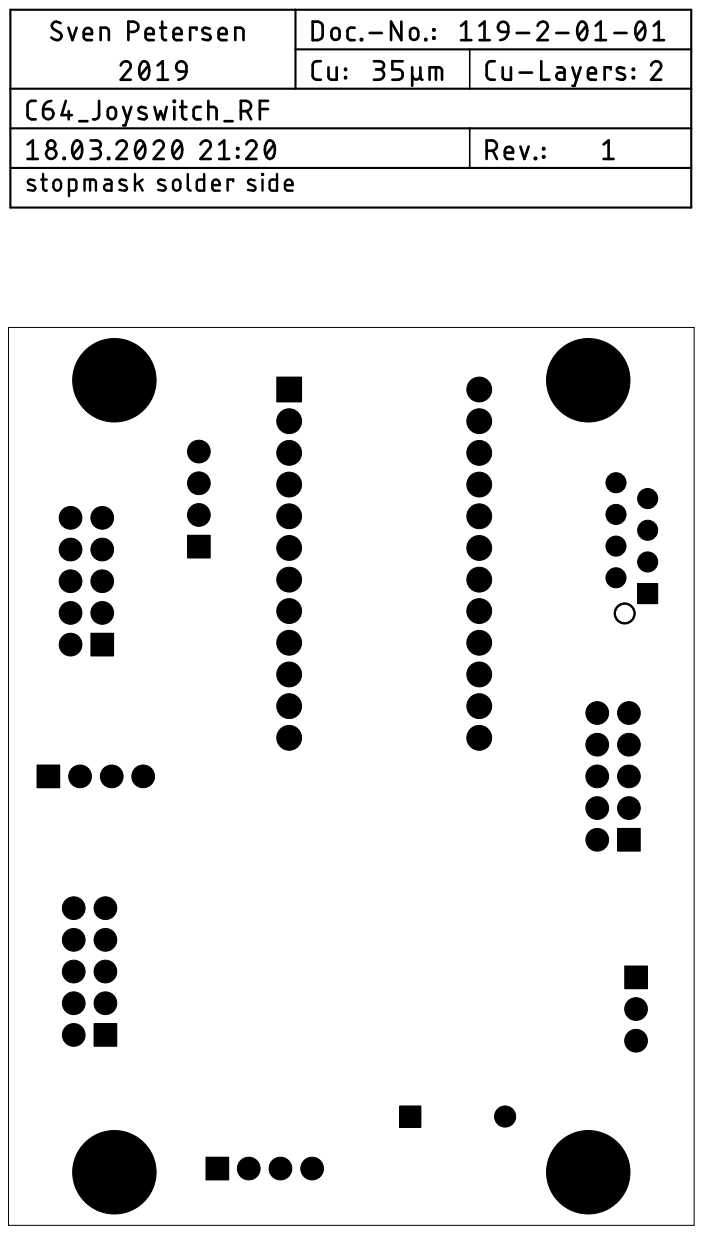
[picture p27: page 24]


C64_JoySW_RF_FunD.docx | | 18.03.2020 21:15
Drafted by Sven Petersen | Page 1 of 1 | Doc.-No.: 119-6-02-01

### C64 – Control Port Switch & Rapid-Fire Rev. 1

### Functional Description

J1 connects top Control Port 1, J2 to Control Port 2. The switching functionality to the four

### direction channels (JOY0…3) of the joystick is realized in IC1 and IC2. A HIGH level on

signal PORT1 switches on the analog switches of IC1 to the active state, while IC2 is switched
off. The joystick signals are available on J1 (JOYA0…3).

A HIGH level on signal PORT2 switches IC1 off (PORT1 is the inverted PORT2), while IC2 is
switched on. JOY0…3 are now present on JOYB0…3 (J2, Port 2).

The analog signals POTX and POTY are switched with the analog switch IC2. Q3 and R1 invert the signal PORT2. A HIGH level on the resulting Signal PORT1 is switching POTX to POTXA and POTY to POTYA on control port 1.

A HIGH level on PORT2 switches POTX to POTXB and POTY to POTYB (control port 2).

Both Fire signals (FIREA and FIREB) are generated by the micro controller module M1, a Pro Micro. Q1 and Q2 serve as switches. HIGH pulses on the signals FIRE1 and FIRE2 respectively issue LOW pulses on FIREA and FIREB respectively. LOW means, that the fire is active.

/LED1 and /LED2 should indicate the active control port. /SWITCH and /RF_ON are active LOW signals from external switches, the purpose is switching between channels and switching on/off the rapid-fire function.

The FIRE signal is issued by the connected joystick. It is active LOW. The controller is supervising this signal and issuing the HIGH level or pulses on FIRE1 or FIRE, depending on the rapid-fire option is switched off or on and the port, which is selected.

### The signal RFSPEED is a voltage level depending on the position of the connected “Speed”

potentiometer. The controller is converting it to digital internally.

J7 carries the I²C bus signals of the controller and supply voltage (+5V) and ground. The purpose is connecting an I²C bus LCD or OLED display. This can serve to indicate the state and rapid-fire rate.
The twin diodes D1…D7 serve as a basic protection of the joystick input. The digital joystick
inputs are connected to 10k pull-up resistors.

IC4 is not necessarily populated. It is an EEPROM and can be used to store parameters that should be non-volatile. It is only required, if the scrip for the Pro Micro supports this feature.

The circuitry around Q5 is driving a piezo buzzer. It is an option and only required, in case the firmware (script) for the Pro Micro supports this feature.

Pos. Qty Value Footprint Ref.-No. Comment

1 1 119-2-01-01 2 Layer PCB Rev. 1 2 layer, Cu 35µ, HASL, 72.0mm x 55.0mm, 1.6mm FR4

2 3 2x5 box connector 2X05WV J1, J2, J3 e.g. Reichelt WSL 10G

3 3 10p IDC receptacle,

2,54mm

(J1), (J2), (J3), (J4) e.g. Reichelt RND 205-00682
4 2 9p D-SUB (female), IDC (J1), (J2) e.g. Reichelt D-SUB BU 09FB
5 1 9p D-SUB (male), IDC (J3) e.g. Reichelt D-SUB ST 09FB

6 1 6410/22-27-2031 6410-3P J4 Molex KK Pin header, 3p., 2.54mm, e.g. Reichelt MOLEX

22272031

7 1 22-01-2031 (J4) Molex Crimp Housing

8 1 Potentiometer, 10k, linear,

6mm axis

(J4) e.g. Reichelt PIH PC16IP061033
9 1 knob for rotary axis 6 mm (J4) e.g. Reichelt KNOPF 10-150B

10 3 6410/22-27-2041 6410-4P J5, J6, J7 Molex KK Pin header, 4p., 2.54mm, e.g. Reichelt MOLEX

22272041

11 3 22-01-2041 (J5), (J6), (J7) Molex Crimp Housing

12 15 2759-TL/0850-0114 (J4-J7) Molex Crimp Terminal (order more than required)

13 2 3mm/green (J5) LED, e.g. Reichelt LED 3MM GN

14 1 30 mm arcade button (J6) From AliExpress, see module description

15 1 miniature slide switch (J6) hole pitch: 19mm

16 1 OLED 0.91", I²C,

SSD1306

(J7) OLED Display, see documentation
17 1 DuPont Crimp Housing 1x4 (OLED Display) AliExpress, ebay, other webshops
18 4 DuPont Crimp Terminals (OLED Display) AliExpress, ebay, other webshops

19 5 100n 805 C1, C2, C3, C4, C6 0805 SMD ceramic capacitor, 25V or better

20 13 10k 805 R1, R2, R3, R4, R5, R6, R7, R8,

R9, R12, R13, R14, R18

0805 SMD chip resistor, 5% or better

21 1 27k 805 R20 0805 SMD chip resistor, 5% or better

22 2 330R 805 R10, R11 0805 SMD chip resistor, 5% or better

## C64 Control Port Switch Rev. 1

## Bill of Material Rev. 1.0

C64_JoySwRF_BOM_v1_0.xlsx

Drafted by Sven Petersen Page 1 of 2

20.03.2020 13:56
Doc.No.: 119-5-01-01.0

Pos. Qty Value Footprint Ref.-No. Comment

## C64 Control Port Switch Rev. 1

## Bill of Material Rev. 1.0

23 1 33R 805 R19 0805 SMD chip resistor, 5% or better

24 1 369-1-008 MICMA08B X3 do not place: MPE, Socket MicroMatch 1.27 mm, 2X04,

straight, e.g. Reichelt MPE 369-1-008

25 7 BAV99 SOT23 D1, D2, D3, D4, D5, D6, D7 Twin diode, SMD SOT23

26 4 BC846B SOT23 Q1, Q2, Q3, Q5 NPN transistor, SMD SOT23. Alternative: BC847B,

BC848B,

27 3 HCF4066BM1 SO-14 IC1, IC2, IC3 4066B SMD, e.g. ST-Micro or NXP, Reichelt SMD 4066

28 1 LL4148 SOD80C D8 SMD Diode

29 1 M24C01-WMN SO-08 IC4 do not place

30 1 PRO_MICRO PRO_MICRO M1 Micro controller module, ebay or other online shops

31 2 1x12 (M1) 12 way socket strip (pitch: 2.54mm), e.g. Reichelt MPE 115-

1-012

32 1 RMP-14P/HT RMP-14P/HT SPK1 KM, e.g. Reichelt SUMMER EPM 121

33 1 3D printed case in the project files. Alternative: Plastic case Reichelt RND

455-00959

34 2 LED mounting clip 5mm e.g. Reichelt MONTAGERING 5MM

35 60cm Wire, AWG24/0.25mm²,

red

for wiring

36 60cm Wire, AWG24/0.25mm²,

black

for wiring

37 9cm Wire, AWG24/0.25mm²,

grey

for wiring

38 9cm Wire, AWG24/0.25mm²,

yellow

for wiring

39 11cm shrinkable sleve for LEDs and switches

40 25cm Ribbon Cable, AWG28,

10p

For joystick and control port connections

C64_JoySwRF_BOM_v1_0.xlsx

Drafted by Sven Petersen Page 2 of 2

20.03.2020 13:56
Doc.No.: 119-5-01-01.0

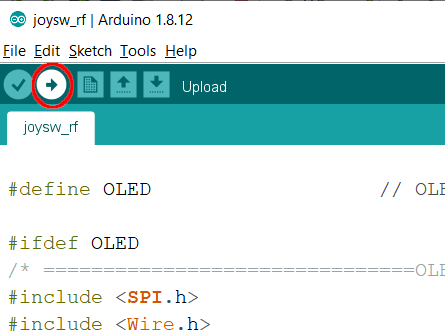
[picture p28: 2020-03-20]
Hardware/Rev. 1/pictures/upload.png

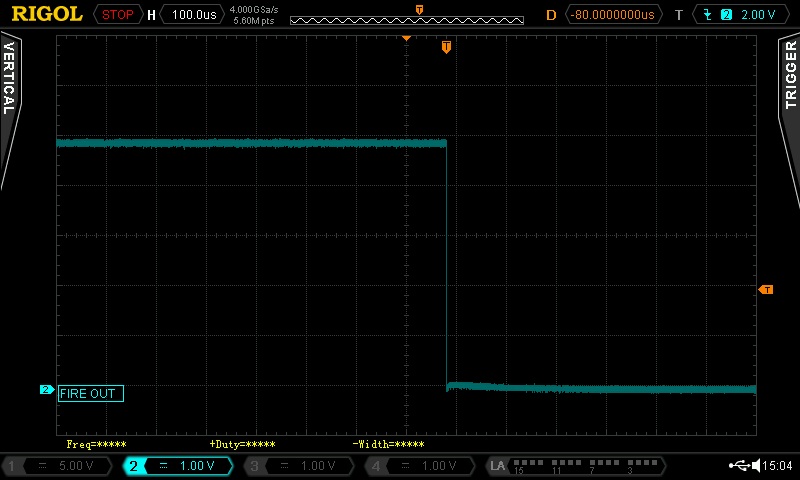
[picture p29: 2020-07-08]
Hardware/Rev. 1/pictures/JSRF_-slope_out_100us.png

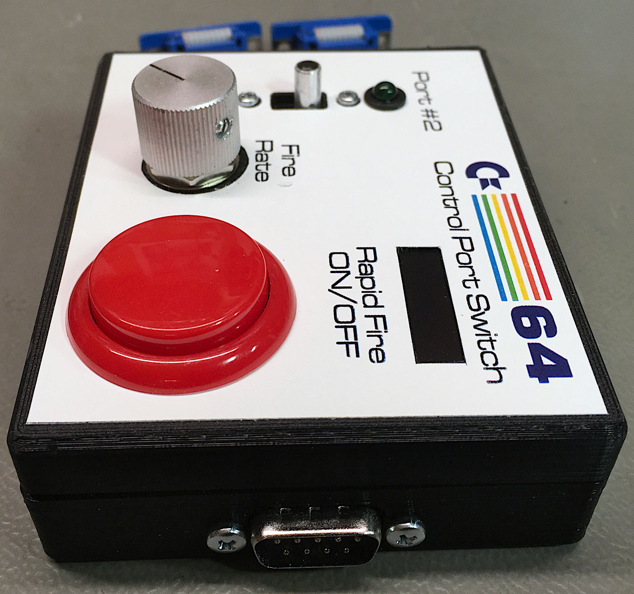
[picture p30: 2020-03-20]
Hardware/Rev. 1/pictures/4140_-_side_view.JPG

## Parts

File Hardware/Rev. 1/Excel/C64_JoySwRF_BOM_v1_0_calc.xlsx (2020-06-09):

C64 Control Port Switch Rev. 1
Bill of Material Rev. 1.0
Pos. | Qty | Value | €/ea | € | Comment
1 | 1 | 119-2-01-01 | 1.00 € | 1.00 € | 2 layer, Cu 35µ, HASL, 72.0mm x 55.0mm, 1.6mm FR4
2 | 3 | 2x5 box connector | 0.10 € | 0.30 € | e.g. Reichelt WSL 10G
3 | 3 | 10p IDC receptacle, 2,54mm | 0.25 € | 0.75 € | e.g. Reichelt RND 205-00682
4 | 2 | 9p D-SUB (female), IDC | 0.66 € | 1.32 € | e.g. Reichelt D-SUB BU 09FB
5 | 1 | 9p D-SUB (male), IDC | 0.58 € | 0.58 € | e.g. Reichelt D-SUB ST 09FB
6 | 1 | 6410/22-27-2031 | 0.22 € | 0.22 € | Molex KK Pin header, 3p., 2.54mm, e.g. Reichelt MOLEX 22272031
7 | 1 | 22-01-2031 | 0.05 € | 0.05 € | Molex Crimp Housing
8 | 1 | Potentiometer, 10k, linear, 6mm axis | 1.15 € | 1.15 € | e.g. Reichelt PIH PC16IP061033
9 | 1 | knob for rotary axis 6 mm | 0.31 € | 0.31 € | e.g. Reichelt KNOPF 10-150B
10 | 3 | 6410/22-27-2041 | 0.25 € | 0.75 € | Molex KK Pin header, 4p., 2.54mm, e.g. Reichelt MOLEX 22272041
11 | 3 | 22-01-2041 | 0.09 € | 0.27 € | Molex Crimp Housing
12 | 15 | 2759-TL/0850-0114 | 0.06 € | 0.90 € | Molex Crimp Terminal (order more than required)
13 | 2 | 5mm/green | 0.12 € | 0.24 € | LED, e.g. Reichelt LED 5MM ST GN
14 | 1 | 30 mm arcade button | 0.85 € | 0.85 € | From AliExpress, see module description
15 | 1 | miniature slide switch | 0.32 € | 0.32 € | hole pitch: 19mm
16 | 1 | OLED 0.91", I²C, SSD1306 | 1.28 € | 1.28 € | OLED Display, see documentation
17 | 1 | DuPont Crimp Housing 1x4 | 0.06 € | 0.06 € | AliExpress, ebay, other webshops
18 | 4 | DuPont Crimp Terminals | 0.06 € | 0.24 € | AliExpress, ebay, other webshops
19 | 5 | 100n | 0.08 € | 0.40 € | 0805 SMD ceramic capacitor, 25V or better
20 | 13 | 10k | 0.02 € | 0.26 € | 0805 SMD chip resistor, 5% or better
21 | 1 | 27k | 0.02 € | 0.02 € | 0805 SMD chip resistor, 5% or better
22 | 2 | 330R | 0.02 € | 0.04 € | 0805 SMD chip resistor, 5% or better
23 | 1 | 33R | 0.02 € | 0.02 € | 0805 SMD chip resistor, 5% or better
24 | 0 | 369-1-008 | 0.00 € | 0.00 € | do not place: MPE, Socket MicroMatch 1.27 mm, 2X04, straight, e.g. Reichelt MPE 369-1-008
25 | 7 | BAV99 | 0.04 € | 0.28 € | Twin diode, SMD SOT23
26 | 4 | BC846B | 0.02 € | 0.08 € | NPN transistor, SMD SOT23. Alternative: BC847B, BC848B,
27 | 3 | HCF4066BM1 | 0.26 € | 0.78 € | 4066B SMD, e.g. ST-Micro or NXP, Reichelt SMD 4066
28 | 1 | LL4148 | 0.04 € | 0.04 € | SMD Diode
29 | 0 | M24C01-WMN | 0.00 € | 0.00 € | do not place
30 | 1 | PRO_MICRO | 4.29 € | 4.29 € | Micro controller module, ebay or other online shops
31 | 2 |  | 0.85 € | 1.70 € | 12 way socket strip (pitch: 2.54mm), e.g. Reichelt MPE 115-1-012
32 | 1 | RMP-14P/HT | 0.67 € | 0.67 € | KM, e.g. Reichelt SUMMER EPM 121
33 | 1 | 3D printed case | 0.00 € | 0.00 € | in the project files. Alternative: Plastic case Reichelt RND 455-00959
34 | 2 | LED mounting clip 5mm | 0.06 € | 0.12 € | e.g. Reichelt MONTAGERING 5MM
35 | 1 | Wire, AWG24/0.25mm², red | 0.20 € | 0.20 € | for wiring
36 | 1 | Wire, AWG24/0.25mm², black | 0.20 € | 0.20 € | for wiring
37 | 1 | Wire, AWG24/0.25mm², grey | 0.10 € | 0.10 € | for wiring
38 | 1 | Wire, AWG24/0.25mm², yellow | 0.10 € | 0.10 € | for wiring
39 | 1 | shrinkable sleve | 0.10 € | 0.10 € | for LEDs and switches
40 | 1 | Ribbon Cable, AWG28, 10p | 0.50 € | 0.50 € | For joystick and control port connections
 |  |  | Total | 20.49 €

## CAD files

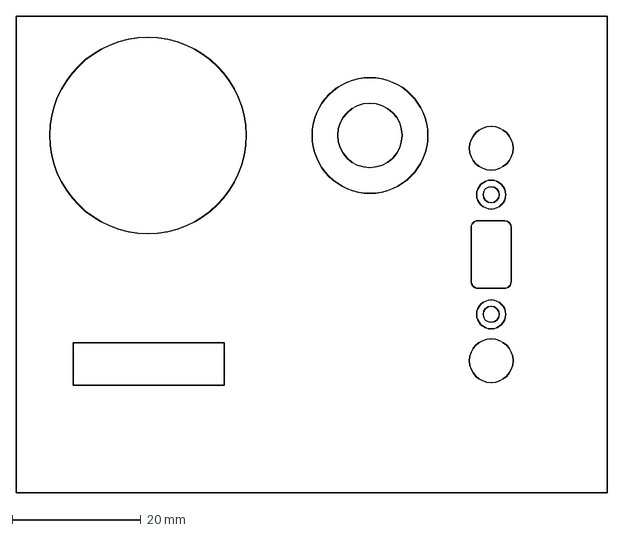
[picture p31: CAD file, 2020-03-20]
case/rev 0/dxf/label_outline.dxf
91.8 x 74.0 mm

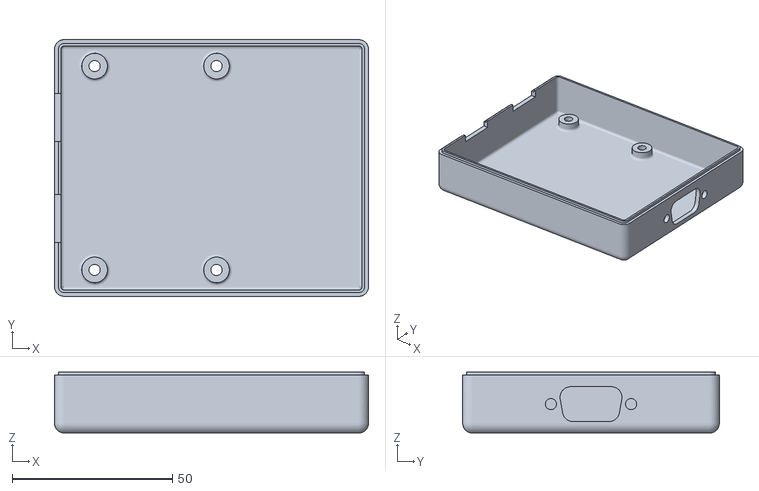
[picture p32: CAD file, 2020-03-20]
case/rev 0/stl/bottom shell.stl
97.8 x 80.0 x 19.0

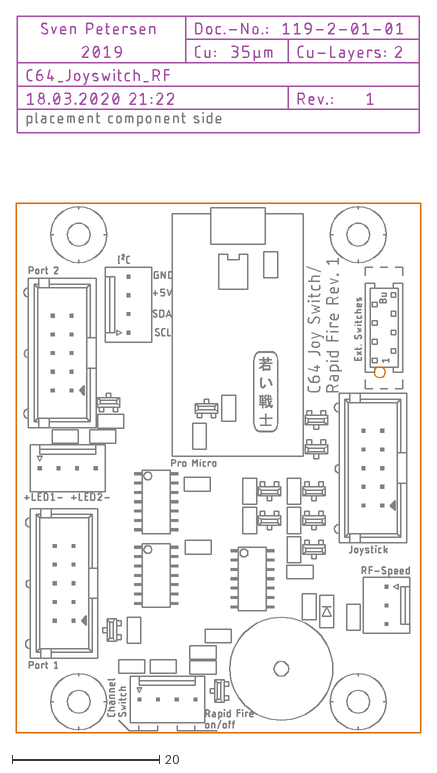
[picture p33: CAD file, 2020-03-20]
Hardware/Rev. 1/dxf/C64_Joyswitch_RF.dxf
55.0 x 97.5

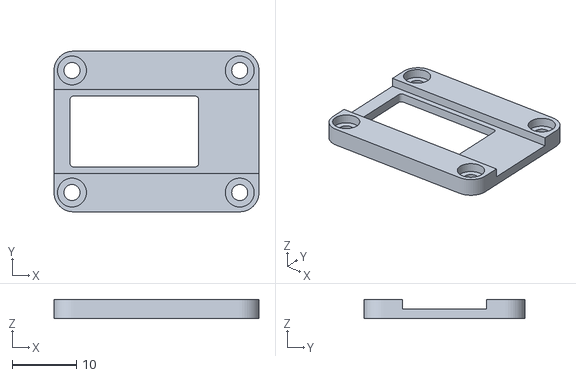
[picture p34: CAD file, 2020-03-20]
case/rev 0/stl/oled_holder.stl
31.9 x 25.0 x 3.00

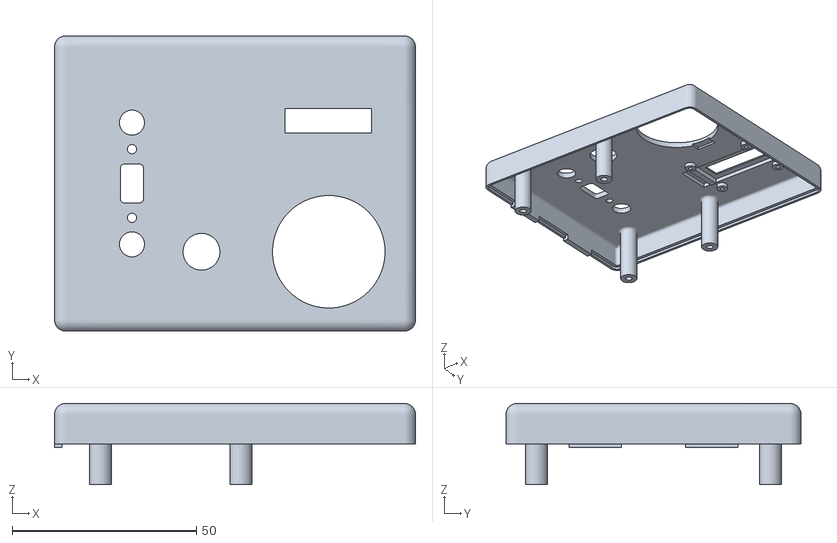
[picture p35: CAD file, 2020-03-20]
case/rev 0/stl/top shell.stl
97.8 x 80.0 x 22.0

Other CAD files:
case/rev 0/Fusion 360/JoySWRF_case v28.f3z

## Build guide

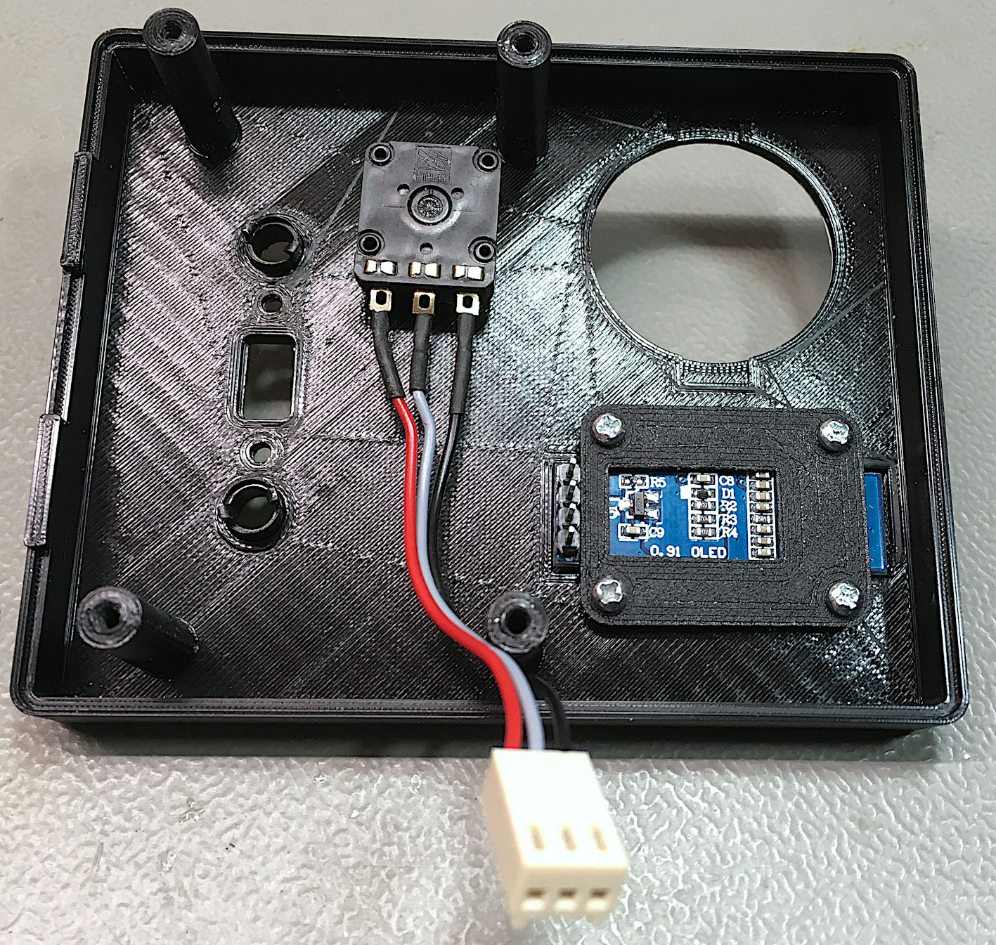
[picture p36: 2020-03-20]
Hardware/Rev. 1/pictures/4133_-_pot_installed.JPG

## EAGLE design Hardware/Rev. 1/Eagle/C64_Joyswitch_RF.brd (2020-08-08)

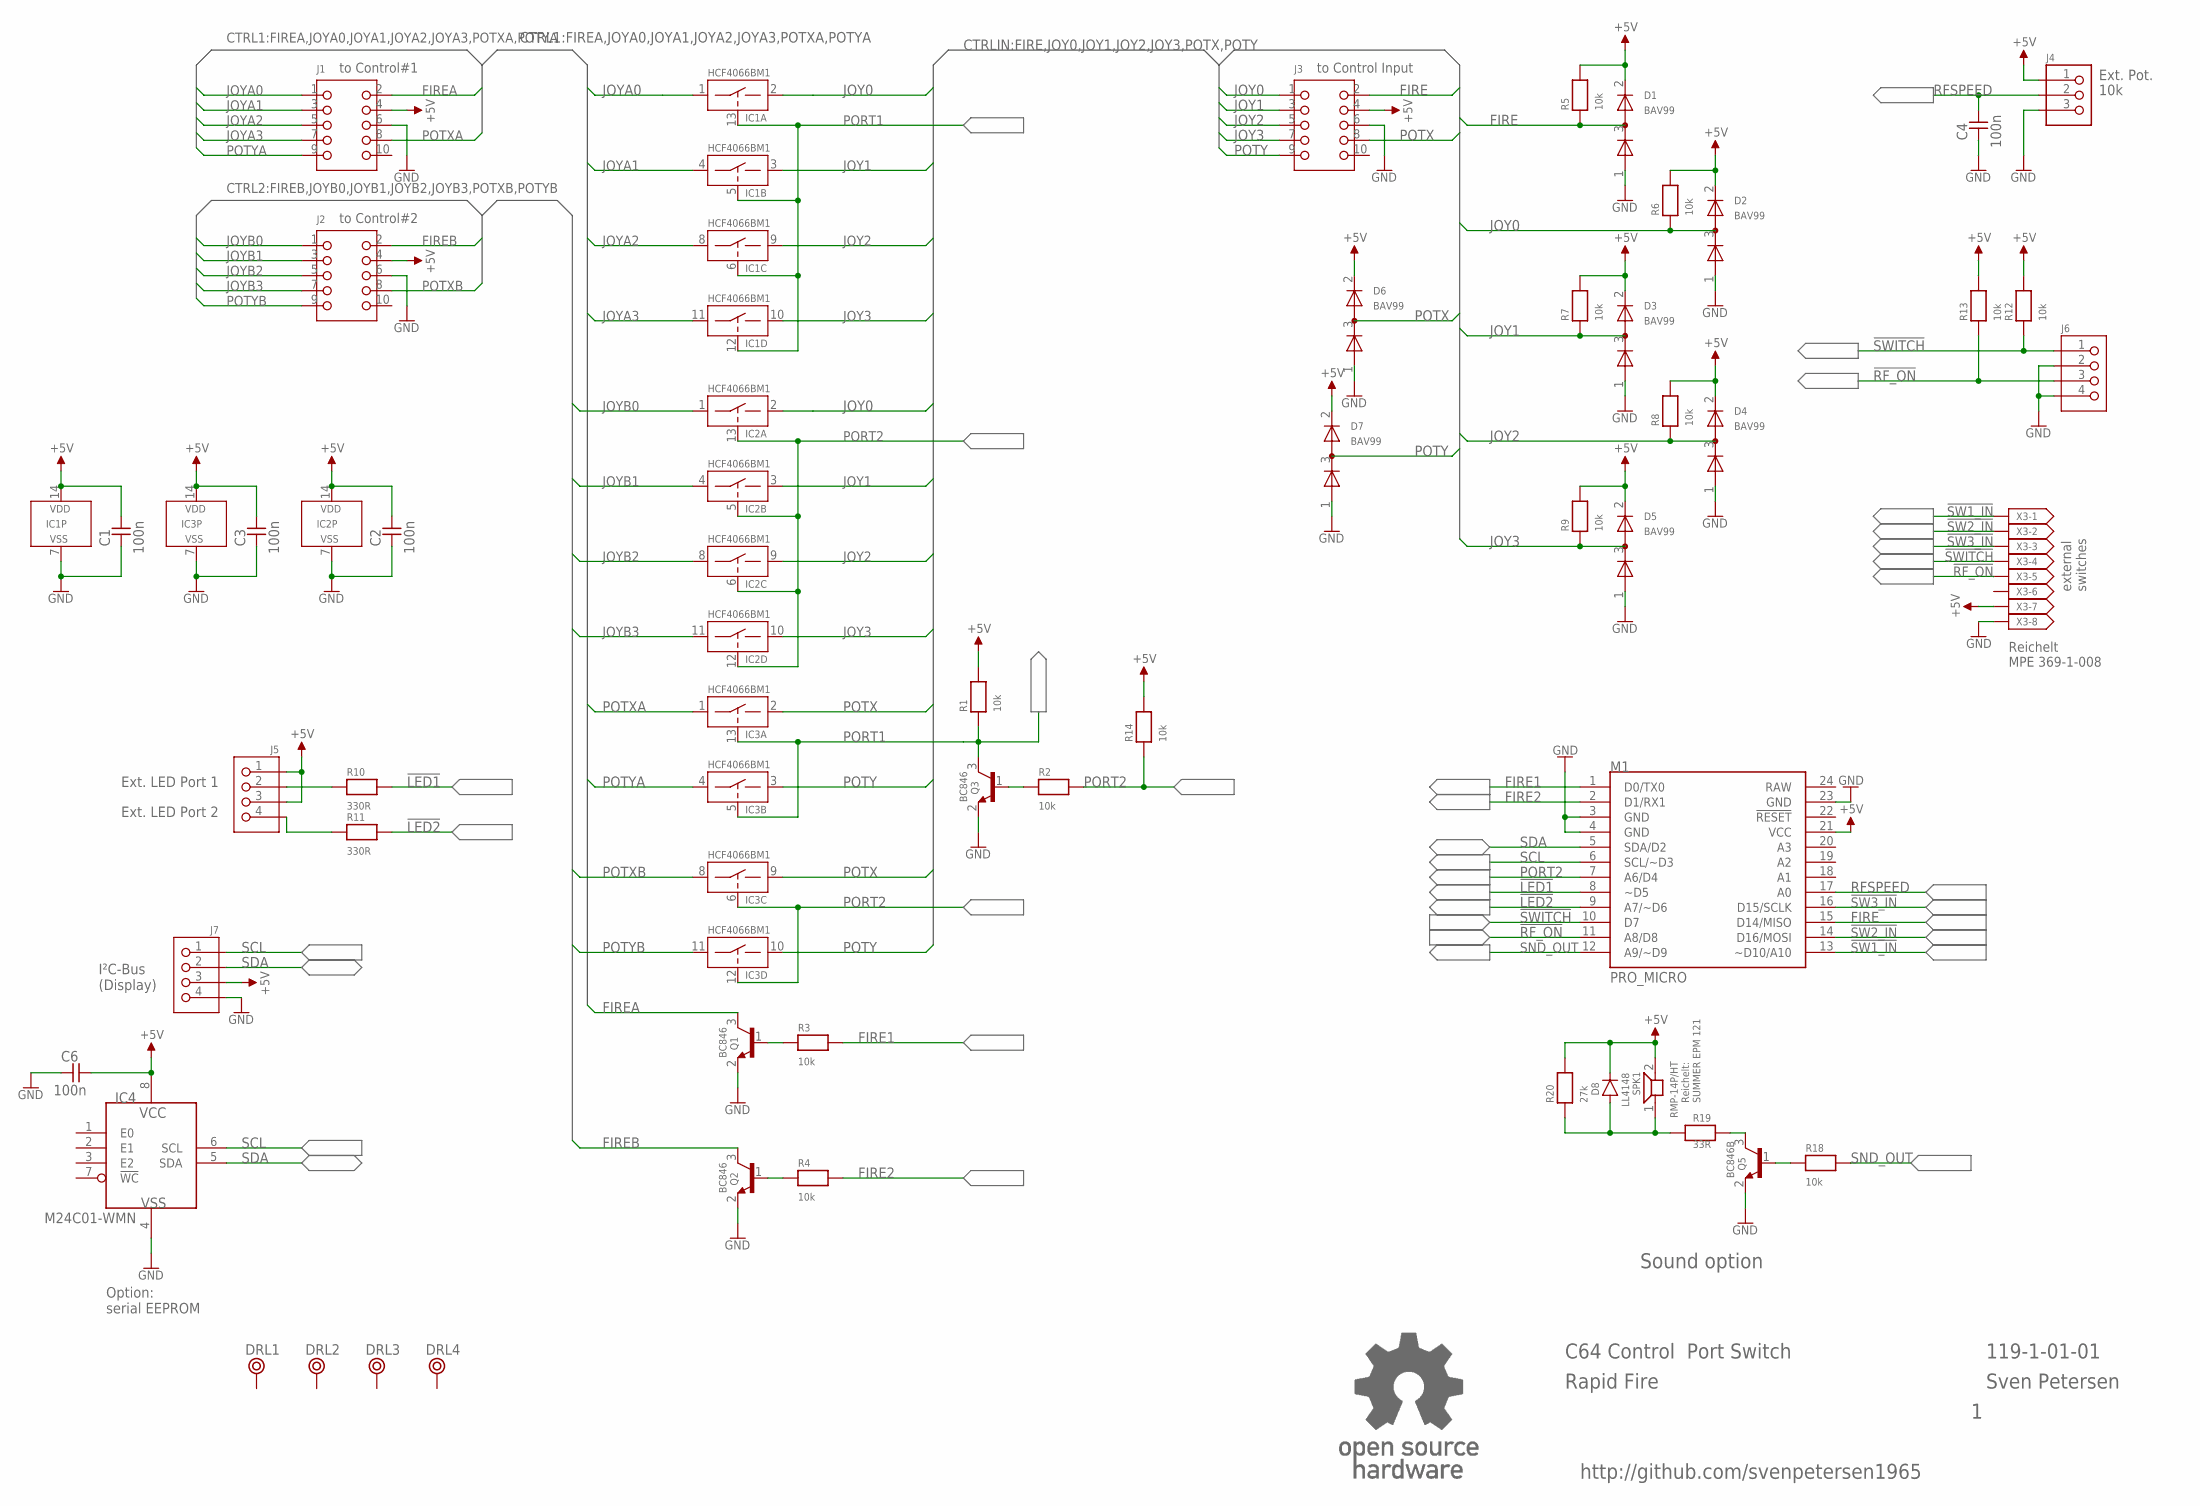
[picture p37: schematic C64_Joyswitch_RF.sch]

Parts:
C1, C2, C3, C4, C6: 100n; 0805
D1, D2, D3, D4, D5, D6, D7: BAV99; SOT23
D8: LL4148; SOD80C
DRL1, DRL2, DRL3, DRL4: BOHR3,1
IC1, IC2, IC3: HCF4066BM1; SO-14
IC4: M24C01-WMN; SO-08
J1, J2, J3: 2X05WV
J4: 6410-3P
J5, J6, J7: 6410-4P
M1: PRO_MICRO
Q1, Q2, Q3: BC846; SOT23
Q5: BC846B; SOT23
R1, R2, R3, R4, R5, R6, R7, R8, R9, R12, R13, R14, R18: 10k; 0805
R10, R11: 330R; 0805
R19: 33R; 0805
R20: 27k; 0805
SPK1: RMP-14P/HT
U$94: OPEN_SOURCE_HW; OPENHW
X3: 369-1-008; MICMA08B

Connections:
!LED1: M1.8 (~D5), R10.2
!LED2: M1.9 (A7/~D6), R11.2
!RF_ON: J6.3, M1.11 (A8/D8), R13.1, X3.5
!SW1_IN: M1.13 (~D10/A10), X3.1
!SW2_IN: M1.14 (D16/MOSI), X3.2
!SW3_IN: M1.16 (D15/SCLK), X3.3
!SWITCH: J6.1, M1.10 (D7), R12.1, X3.4
+5V: C1.2, C2.2, C3.2, C6.2, D1.2 (K), D2.2 (K), D3.2 (K), D4.2 (K), D5.2 (K), D6.2 (K), D7.2 (K), D8.K, IC1.14 (VDD), IC2.14 (VDD), IC3.14 (VDD), IC4.8 (VCC), J1.4, J2.4, J3.4, J4.1, J5.1, J5.3, J7.3, M1.21 (VCC), R1.2, R5.2, R6.2, R7.2, R8.2, R9.2, R12.2, R13.2, R14.2, R20.2, SPK1.2, X3.7
FIRE: D1.3 (KA), J3.2, M1.15 (D14/MISO), R5.1
FIRE1: M1.1 (D0/TX0), R3.2
FIRE2: M1.2 (D1/RX1), R4.2
FIREA: J1.2, Q1.3 (C)
FIREB: J2.2, Q2.3 (C)
GND: C1.1, C2.1, C3.1, C4.1, C6.1, D1.1 (A), D2.1 (A), D3.1 (A), D4.1 (A), D5.1 (A), D6.1 (A), D7.1 (A), IC1.7 (VSS), IC2.7 (VSS), IC3.7 (VSS), IC4.4 (VSS), J1.6, J2.6, J3.6, J4.3, J6.2, J6.4, J7.4, M1.3 (GND), M1.4 (GND), M1.23 (GND), Q1.2 (E), Q2.2 (E), Q3.2 (E), Q5.2 (E), X3.8
JOY0: D2.3 (KA), IC1.2 (B), IC2.2 (B), J3.1, R6.1
JOY1: D3.3 (KA), IC1.3 (B), IC2.3 (B), J3.3, R7.1
JOY2: D4.3 (KA), IC1.9 (B), IC2.9 (B), J3.5, R8.1
JOY3: D5.3 (KA), IC1.10 (B), IC2.10 (B), J3.7, R9.1
JOYA0: IC1.1 (A), J1.1
JOYA1: IC1.4 (A), J1.3
JOYA2: IC1.8 (A), J1.5
JOYA3: IC1.11 (A), J1.7
JOYB0: IC2.1 (A), J2.1
JOYB1: IC2.4 (A), J2.3
JOYB2: IC2.8 (A), J2.5
JOYB3: IC2.11 (A), J2.7
unnamed: Q3.1 (B), R2.1
unnamed: Q1.1 (B), R3.1
unnamed: Q2.1 (B), R4.1
unnamed: J5.2, R10.1
unnamed: J5.4, R11.1
unnamed: Q5.1 (B), R18.1
unnamed: Q5.3 (C), R19.2
unnamed: D8.A, R19.1, R20.1, SPK1.1
PORT1: IC1.5 (EN), IC1.6 (EN), IC1.12 (EN), IC1.13 (EN), IC3.5 (EN), IC3.13 (EN), Q3.3 (C), R1.1
PORT2: IC2.5 (EN), IC2.6 (EN), IC2.12 (EN), IC2.13 (EN), IC3.6 (EN), IC3.12 (EN), M1.7 (A6/D4), R2.2, R14.1
POTX: D6.3 (KA), IC3.2 (B), IC3.9 (B), J3.8
POTXA: IC3.1 (A), J1.8
POTXB: IC3.8 (A), J2.8
POTY: D7.3 (KA), IC3.3 (B), IC3.10 (B), J3.9
POTYA: IC3.4 (A), J1.9
POTYB: IC3.11 (A), J2.9
RAW: M1.24 (RAW)
RFSPEED: C4.2, J4.2, M1.17 (A0)
SCL: IC4.6 (SCL), J7.1, M1.6 (SCL/~D3)
SDA: IC4.5 (SDA), J7.2, M1.5 (SDA/D2)
SND_OUT: M1.12 (A9/~D9), R18.2

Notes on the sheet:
to Control#1
to Control#2
to Control Input
Ext. Pot.
10k
Ext. LED Port 1
Ext. LED Port 2
I²C-Bus (Display)
C64 Control Port Switch
Rapid Fire
Sven Petersen
119-1-01-01
external switches
Reichelt MPE 369-1-008
Reichelt: SUMMER EPM 121
Sound option
Option: serial EEPROM
http://github.com/svenpetersen1965

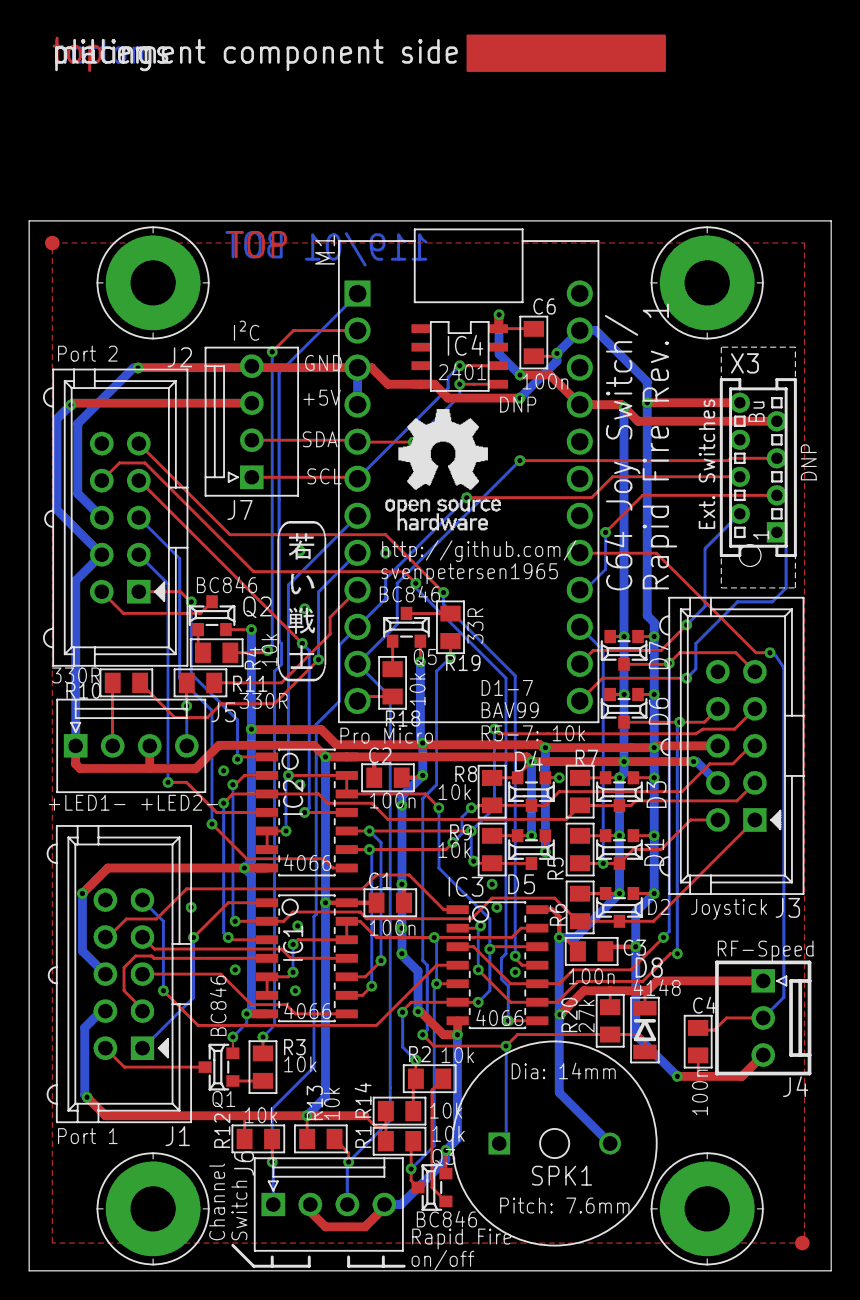
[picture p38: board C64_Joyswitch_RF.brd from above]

Board: 2 copper layers, 55.0 x 72.0 mm, 58 parts (0 on the bottom side), 46 nets.

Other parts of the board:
U$65: 2LAYER
U$66, U$67: SMD_REF_R1MM
U$68: PCB-TITLE/
U$93: SVEN_TAG

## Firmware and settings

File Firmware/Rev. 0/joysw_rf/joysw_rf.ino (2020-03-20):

#define OLED                   // OLED display attached. If not, comment out

#ifdef OLED
/* ===============================OLED========================================== */
#include <SPI.h>
#include <Wire.h>
#include <Adafruit_GFX.h>       // https://github.com/adafruit/Adafruit-GFX-Library
#include <Adafruit_SSD1306.h>   // https://github.com/adafruit/Adafruit_SSD1306
#define SCREEN_WIDTH 128        // OLED display width, in pixels
#define SCREEN_HEIGHT 32        // OLED display height, in pixels

/* ==== The 64 logo ==== */
#define LOGO_HEIGHT   30
#define LOGO_WIDTH    34
static const unsigned char PROGMEM logo_bmp[] =
{ B00000000, B00000000, B11111001, B11100000, B00000000,
B00000000, B00000001, B11110011, B11001000, B00000000,
B00000000, B00000011, B11100111, B10011000, B00000000,
B00000000, B00000111, B11001111, B00111000, B00000000,
B00000000, B00001111, B10011110, B01111000, B00000000,
B00000000, B00011111, B00111100, B01111000, B00000000,
B00000000, B00111110, B01111000, B01111000, B00000000,
B00000000, B01111100, B11110000, B01111000, B00000000,
B00000000, B11111001, B11100000, B01111000, B00000000,
B00000001, B11110011, B11000000, B01111000, B00000000,
B00000011, B11100111, B11000000, B01111000, B00000000,
B00000111, B11001111, B11000000, B01111111, B11000000,
B00001111, B10011111, B11111111, B11111111, B10000000,
B00011111, B00111111, B11111111, B11111111, B00000000,
B00111110, B01111111, B11111111, B11111110, B00000000,
B00111100, B10000111, B11111111, B11111100, B00000000,
B01111000, B00000001, B11110000, B01111000, B00000000,
B01111000, B00000000, B11110000, B01111000, B00000000,
B01110000, B00000000, B01111000, B01111000, B00000000,
B11110000, B00000000, B01111000, B01111000, B00000000,
B11110000, B00000000, B01111000, B01111000, B00000000,
B11110000, B00000000, B01111000, B01111000, B00000000,
B01111000, B00000000, B01111000, B01111000, B00000000,
B01111000, B00000000, B11111000, B01111000, B00000000,
B01111100, B00000001, B11110000, B01111000, B00000000,
B00111111, B00000111, B11110000, B01111000, B00000000,
B00011111, B11111111, B11100000, B01111000, B00000000,
B00001111, B11111111, B11000000, B01111000, B00000000,
B00000111, B11111111, B00000000, B01111000, B00000000,
B00000000, B11111000, B00000000, B01111000, B00000000 };

// Declaration for an SSD1306 display connected to I2C (SDA, SCL pins)
#define OLED_RESET     -1 // Reset pin # (or -1 if sharing Arduino reset pin)
Adafruit_SSD1306 display(SCREEN_WIDTH, SCREEN_HEIGHT, &Wire, OLED_RESET);

/*
 * show the title screen with lofo on OLED
 */
void showLogo(void) {
  display.clearDisplay();                                 // clear OLED
  display.drawBitmap(                                     // place the 64 logo in the middle of the OLED
    (display.width()  - LOGO_WIDTH ) /2,
    (display.height() - LOGO_HEIGHT) /2,
    logo_bmp, LOGO_WIDTH, LOGO_HEIGHT, 1);
  display.display();                                      // display it!
  delay(2000);                                            // wait 2 secs 
  display.clearDisplay();                                 // clear OLED
  display.setCursor(10,6);                                // position the cursor
  display.setTextSize(1);                                 // smalest text
  display.setTextColor(SSD1306_WHITE);                    // text color is white
  display.println(F("http://"));                          // put http://tech.guitarsite.de on oled
  display.setCursor(10,16);
  display.println(F("tech.guitarsite.de")); 
  display.display();                                      // display it
}

/*
 * write thet "Fire Rate" etc. on oled. 
 */
void writeText(void) {
  display.clearDisplay();                 //clear OLED
  display.setTextSize(2);                 // middle text size
  display.setTextColor(SSD1306_WHITE);    // Draw white text
  display.setCursor(7,0);                 // Start at top-left corner
  display.cp437(true);                    // Use full 256 char 'Code Page 437' font
  display.println(F("Fire rate:"));       // the text
  display.setCursor(66,18);               // 2nd line
  display.println(F("r/min"));            // the unit (rounds per minute)
  display.display();                      // display it
 }

/*
 *  write the fire rate to the OLED
 */
void writeFireRate(int rf_interval) {
  int cad;
  cad = 30000/(rf_interval);                              // calculate the fire rate in rounds per minute from the half period time
  display.fillRect( 3, 18, 60, 16, SSD1306_BLACK );       // clear the space for the fire rate: draw a black rectangle
  if (cad == 0) {
    display.setCursor(15,18);
    display.println(F("OFF"));                            // show OFF
    display.display(); 
  }
  else {
    if (cad < 10) { display.setCursor(3+3*12,18); }       // position the cursor (the fire rate is aligned right)
    else if (cad < 100) { display.setCursor(3+2*12,18); }
    else if (cad < 1000) { display.setCursor(3+12,18); }
    else display.setCursor(3,18); 
    display.println( cad );//                             // write fire rate to the display
  }
  display.display();                                      // display it
}

void writeStatusOff( void ){
  display.clearDisplay();
  display.clearDisplay();                 //clear OLED
  display.setTextSize(4);                 //large text size
  display.setCursor(28,2);                // position sursor
  display.println(F("OFF"));              // write OFF to OLED
  display.display(); 
}
/* ===============================OLED========================================== */
#endif  // ifdef OLED


#define rfspeed  A0                       // potentiometer input
#define blink_time 200                    // blink time (msecs)
#define snd_time 250                      // sound time (msecs)
#define debounce 30
#define rate_cycle 250                    // display the fire rate every <rate_cycle> msecs


int fire1 = 1;   // fire port #1 (active high)
int fire2 = 0;   // fire port #2 (active high)
int port2 = 4;   // port switch #1 = low, #2 = high
int nled1 = 5;   // led port #1 (active low)
int nled2 = 6;   // led port #2 (active low)
int nswitch = 7; // channel select switch (#1 = low, #2 = high)  
int nrf_on = 8;  // rapid fire toggle switch (active low)
int snd_out = 9; // output for piezo speaker
int nfire = 14;  // fire input from joystick

// int wait_time = 500;
int channel = 2;                  // default channel is port #2
int rapid_fire = 0;               // rapid fire flag
int loop_counter = blink_time;    // some loop counter for blinking the LEDs
int rapid_fire_interval = 200;    // rapid fire interval in mili seconds
int rf_loop_counter = 200;        // loop counter for rapid fire
int previous_fire_state = 1;      // previous state of the fire button
int debounce_counter = debounce;  // counter for debouncing rf switch
int rf_toggle = 0;                // flag to let the rapid fire only toggle once before the switch is released
int blink_state = 0;              // state of the led blink (while rapid fire)
int rf_state = 1;                 // state of rapid fire, 1 = fire, 0 = not fire
int pot_value;                    // value of the potentiometer
int fire_output = HIGH;           // fire output level
int snd_counter = 0;              // sound count down
int display_counter = 0;          // display cycle coundown
int last_rate = 0;                // last displayed fire rate

void setup() {
  digitalWrite(fire1, LOW);       // initialize with low (= inactive)
  pinMode(fire1,  OUTPUT);        // fire port #1 is an output
  
  digitalWrite(fire2, LOW);       // initialize with low (= inactive)
  pinMode(fire2, OUTPUT);         // fire port #2 is an output
  
  digitalWrite(port2, HIGH);      // initialize with high (= Port #2 is selected by default)
  pinMode(port2, OUTPUT);         // this signal determins which port is used. It is an output

  digitalWrite(nled1, HIGH);      // initialize with high (= led1 is off)
  pinMode(nled1, OUTPUT);         // led port #1 is an output

  digitalWrite(nled2, LOW );      // initialize with low (= led2 is on)
  pinMode(nled2, OUTPUT);         // led port #2 is an output
  
  pinMode(nswitch, INPUT);        // channel select switch is an input
  pinMode(nrf_on,  INPUT);        // rapid fire toggle switch is an input
  pinMode(nfire,   INPUT);        // nfire is an input
  
  tone( snd_out, 4000 );          // 1kz sound on snd_out
  delay( 250 );
  noTone( snd_out );

#ifdef OLED
  if(!display.begin(SSD1306_SWITCHCAPVCC, 0x3C)) { // Address 0x3C for 128x32
    while(1) {                      // Don't proceed, loop forever
       tone( snd_out, 4000 );       // 1kz sound on snd_out
       delay( 250 );
       tone( snd_out, 2000 );       // 1kz sound on snd_out
       delay( 250 );
    }
  }
  showLogo();
#endif
}

void loop() {
   // test the channel switch and change ports if required
   if  (digitalRead( nswitch ) == LOW) {  // port #1 selected
      if (channel == 2) {                 // port has changed
         digitalWrite( fire2, LOW );      // no more firing at port #2
         digitalWrite( nled2, HIGH );     // switch off led2
         digitalWrite( nled1, LOW );      // switch on LED of Port#1
         digitalWrite( port2, LOW );      // switch joystick signals to port #1
         channel = 1;                     // store channel number
      }
   }
   else {                                 // port #2 selected
      if (channel == 1) {                 // port has changed
         digitalWrite( fire1, LOW );      // no more firing at port #1
         digitalWrite( nled1, HIGH );     // switch off led1
         digitalWrite( nled2, LOW );      // switch on LED of Port#2
         digitalWrite( port2, HIGH );     // switch joystick signals to port #2
         channel = 2;                     // store channel number
      }
   }

   pot_value = analogRead(rfspeed);                             // read the value of the potentiometer
   rapid_fire_interval = map( pot_value, 0, 1023, 200, 20 );    // calculate the rapiod fire (half) period in millisecs
   if (rapid_fire==1) {                                         // if rapid fire is switched on
     if (display_counter == 0) {                                // the rate is only displayed every <rate_cycle> msecs
#ifdef OLED
        writeFireRate(rapid_fire_interval);                     // display
#endif
        display_counter = rate_cycle;                           // reset counter
     }
     else {
       display_counter--;                                       // decrement counter
     }
   }

   // test the fire button and fire on the selected channel, if required
   if (digitalRead( nfire ) == LOW ) {                     // fire button pressed?
      if (rapid_fire == 1) {
         if (previous_fire_state == 1) {                   // did the button status change?
            rf_loop_counter = rapid_fire_interval;         // yes: reset the rapid fire loop counter
            rf_state = 1;                                  // and start firing immideately
         }
         else if (rf_loop_counter > 0) {                   // no:
            rf_loop_counter--;                             // decrement counter
         }
         else {                                            // if counter is zero
            rf_loop_counter = rapid_fire_interval;         // reset the rapid fire loop counter
            if (rf_state == 1) {                           // and toggle the rf_state
              rf_state = 0;
            }
            else {
              rf_state = 1;
            }
         }
      }
      fire_output = (rapid_fire == 0) || (rf_state == 1);   // press fire if rapid fire is off or rapid fire state is on
      if (channel == 1) {                                   // is channel 1 selected
        digitalWrite( fire1, fire_output );                 // fire on port #1 
      }
      else {                                                // channel 2 is selected
        digitalWrite( fire2, fire_output );                 // fire on port #2 
      }
      previous_fire_state = 0;                               
   }
   else {                                                   // no fire button pressed
     digitalWrite( fire1, LOW );                            // switch off both fire outputs
     digitalWrite( fire2, LOW );
     previous_fire_state = 1;
   }

   // test the rapid fire button and toggle rapid fire mode, if required
   if (digitalRead( nrf_on ) == LOW) {                      // rapid fire toggle switch pressed? 
      if (rf_toggle == 0) {
        if (debounce_counter > 0) {                         // debounce time not elapsed
          debounce_counter--;                               // decrement debounce counter
        }
        else {                                              // debounce time elapsed
          if (rapid_fire == 0) {                            // toggle rapid fire mode
            rapid_fire = 1;                                 // on
            blink_state = 0;                                // set blink state to off 
            rf_state = 1;                                   // set rf state: fire immideately
            loop_counter = rapid_fire_interval;             // initialize loop_counter
            snd_counter = snd_time;                         // start delay for sound
            tone( snd_out, 4000 );                          // Tone on
            display_counter = 0;           
#ifdef OLED            
            writeText();                                    // write "Fire rate: ..... r/min" on OLED dispklay
#endif              
          }
          else {
            rapid_fire = 0;
#ifdef OLED            
            writeStatusOff();                              // write "OFF" on OLED display 
#endif             
            if (channel == 1) {
              digitalWrite( nled1, LOW );                  // switch on LED of Port#1
            }
            else {
              digitalWrite( nled2, LOW );                  // switch on LED of Port#2
            }
          }
          rf_toggle = 1;                                   // inhibit further toggling until switch was released
        }
      }
   }
   else {
     debounce_counter = debounce;                           // reset debounce counter
     rf_toggle = 0;                                         // reset rf_toggle (allow next toggle of rapid fire state)
   }

   // blink the channel LED if rapid fire is on
   if  (rapid_fire == 1) {                                  // if rapid fire, then blinking
      if (loop_counter > 0) {                               // loop_counter elapsed?
        loop_counter--;                                     // no: decrement
      }
      else {                                                // yes:
        loop_counter = rapid_fire_interval;                 // initialize loop_counter
        if (blink_state == 0) {                             // toggle blink state
          blink_state = 1;                                  // led off
        }
        else {
          blink_state = 0;                                  // led on
        }
      }
      if (channel == 1)                                     // if channel 1 select, then blibk LED1
        if (blink_state == 0) {                             // switch on and off depending on the blink state
          digitalWrite( nled1, HIGH );     
        }
        else {
          digitalWrite( nled1, LOW );  
        }
      else {                               
        if (blink_state == 0) {
          digitalWrite( nled2, HIGH );
        }
        else {
          digitalWrite( nled2, LOW );  
        }  
      }
   }
   if (snd_counter > 0) {                                    // count down for the beeper
      if (--snd_counter == 0) {
        noTone( snd_out );                                   // if the count down is elaped, sound off 
      }
   }
   // this is the 1 mili second loop delay
   delay( 1 ); // delay 1 msec                               // the 1msec loop delay
}

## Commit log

2020-06-09 Replaced the obsolete Molex, Calculation
    The cheaper KF2510 series can replace the Molex Pin header and crimp housings. This was chanced in the BOM. The component price was calculated (08.06.2020)
    [C64_JoySwRF_BOM_v1_0_calc.xlsx, C64_JoySwRF_BOM_v1_1.xlsx]
2020-08-08 Silk Screen Update
    [C64_Joyswitch_RF.brd, C64_Joyswitch_RF.sch]
